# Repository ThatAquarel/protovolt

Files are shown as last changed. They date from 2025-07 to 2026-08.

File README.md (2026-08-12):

[ProtoV MINI][website]

# A power supply to catalyze prototyping

[][release]
[][ci]
[][chat]
[][cs]

**ProtoV MINI** is a credit card-sized, dual-channel lab power supply for
electronics prototyping and field testing. It is powered by USB-C PD and runs
open firmware written in Rust.

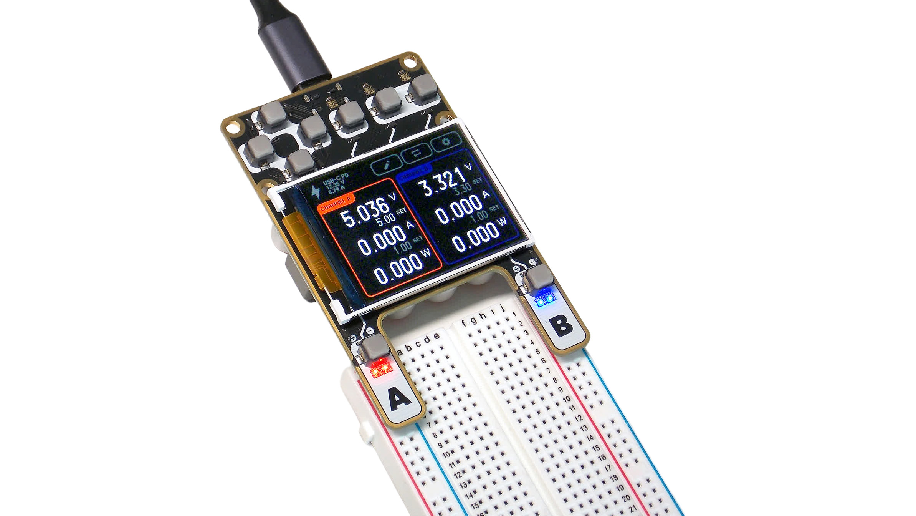
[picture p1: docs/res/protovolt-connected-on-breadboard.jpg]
ProtoV MINI powering a breadboard


## Getting Started

Start with the [quick-start guide](docs/quick_start.md) to connect a USB-C PD
power supply, optionally link ProtoV MINI to a computer, and open
[ProtoV App](https://protov.app).

## Development

```sh
git clone https://github.com/flakeblade/protov.git
cd protov
rustup target add thumbv6m-none-eabi
cargo install just
just build
```
See [development](#development-1) for prerequisites, tests, and common
commands. Run `just --list` to see every available recipe.

## Documentation

### Guides

- [Device overview](docs/product.md) — hardware overview, and dimensions
- [Quick start](docs/quick_start.md) — quickstart wiring guide
- [Interface guide](docs/interface_guide.md) — normal UI flow with example screens
- [Troubleshooting](docs/troubleshooting.md) — faults, protection, and boot failures

### Development

Project structure
- [Repository index, and workspace modules](docs/repository.md)
- [Firmware roadmap](docs/roadmap.md)

Installation, building, and uploading
1. [Toolchain installation, and building](docs/development.md)
2. [Release bundling, and firmware signature](docs/releases.md)
3. [Flashing to hardware](docs/flashing.md)

### References

Hardware compatibility
- [Power delivery sources](docs/compatibility.md)
- [Breadboards](docs/compatibility.md)

Design documentation
- [Hardware and dimensions](docs/hardware.md)
- [SCPI protocol reference](protov-scpi/PROTOCOL.md)

Support
- [Troubleshooting](docs/troubleshooting.md)

<!-- - [Product overview](docs/product.md)
    
- [Flashing](docs/flashing.md)

- [SCPI protocol](protov-scpi/PROTOCOL.md)
- [SCPI crate](protov-scpi/README.md)
- [Bootloader](protov-bootloader/README.md)
- [Flash layout and firmware verification](protov-nvm/README.md) -->

## Contributing

Bug reports and contributions are welcome in the
[GitHub repository](https://github.com/flakeblade/protov).

> [!WARNING]
> Modifying or uploading firmware is done entirely at your own risk. An
> incompatible image can leave the device inoperable and may require USB
> BOOTSEL or SWD recovery. Bypassing current, voltage, temperature, power, or
> other protection limits can damage ProtoV MINI, connected equipment, or
> wiring and may create an electrical or fire hazard. Verify the hardware
> revision, understand every safety-related change, and test conservatively.

## License

[Eclipse Public License 2.0](LICENSE) © Alex Xia — [@ThatAquarel](http://github.com/thataquarel)

<p align="center">
  <a href="https://flakeblade.com">
    Flake & Blade Robotics Design
  </a>
  <br>
  A Flake &amp; Blade Robotics Design project
</p>

[fbrd]: https://flakeblade.com
[release-badge]: https://github.com/flakeblade/protov/actions/workflows/release.yml/badge.svg
[release]: https://github.com/flakeblade/protov/actions/workflows/release.yml
[ci-badge]: https://github.com/flakeblade/protov/actions/workflows/ci.yml/badge.svg
[ci]: https://github.com/flakeblade/protov/actions/workflows/ci.yml
[chat-badge]: https://img.shields.io/badge/chat-discussions-success.svg
[chat]: https://github.com/flakeblade/protov/discussions
[cs-badge]: https://img.shields.io/badge/Crowd-Supply-099?labelColor=555
[cs]: https://www.crowdsupply.com/flake-and-blade-robotics-design/protov-mini
[cover]: docs/res/logo/protov_mini_cover.svg
[website]: https://protov.app

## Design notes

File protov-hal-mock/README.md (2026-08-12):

# protov-hal-mock

`protov-hal-mock` is a host-side ProtoV MINI simulator. It runs the
[`protov-core`](../protov-core/README.md) product logic without RP2040 hardware
and exposes WebSocket endpoints for
[`protov_app`](https://github.com/flakeblade/protov_app), integration tests,
and protocol development.

## Run

```sh
just build-mock
just run-mock
```

The default listeners are:

- `ws://127.0.0.1:8765` — SCPI transport
- `ws://127.0.0.1:8766` — JSON control and state management

Override them with `--bind`, `--scpi-port`, and `--control-port`, or the
`PROTOV_MOCK_SCPI_PORT` and `PROTOV_MOCK_CTRL_PORT` environment variables.

> [!TIP]
> Use the mock for application and SCPI work before connecting real power
> hardware. It follows the same core state machine and is faster to reset,
> inspect, and automate.

## UI state renders

YAML presets under [`states/`](states) describe full device snapshots (SCPI
channels, interface fields, power input, and UI mode). Extend
[`states/default.yaml`](states/default.yaml) for deltas.

Export headless PNG catalog images for documentation:

```sh
just render-ui
```

This writes PNGs to [`docs/res/ui/`](../docs/res/ui/) and refreshes
[`docs/ui-states.md`](../docs/ui-states.md).

## How it works

The server maintains four independent mock-device slots. A SCPI WebSocket
connection acquires an available slot and releases it when disconnected. The
control endpoint can inspect, load, reset, or release slots with JSON messages.
Ready-made snapshots for common states live under [`states/`](states).

- [`src/main.rs`](src/main.rs) — command-line options and server lifecycle
- [`src/server.rs`](src/server.rs) — listener setup and shutdown
- [`src/pool.rs`](src/pool.rs) — mock-device slots and identities
- [`src/device.rs`](src/device.rs) — simulated device state and command handling
- [`src/ws/scpi.rs`](src/ws/scpi.rs) — SCPI WebSocket sessions
- [`src/ws/control.rs`](src/ws/control.rs) — JSON control WebSocket
- [`src/state/`](src/state) — snapshots and control request schema
- [`src/scpi/`](src/scpi) — framing, routing, tasks, and simulated DFU
- [`src/telemetry.rs`](src/telemetry.rs) — generated measurements
- [`src/render.rs`](src/render.rs) — headless UI render pipeline (`render-ui` feature)

SCPI commands follow the
[ProtoV wire protocol](../protov-scpi/PROTOCOL.md). The mock uses the
[`protov-scpi`](../protov-scpi/README.md) parser and host-compatible types.
Control requests support `ping`, `status`, `reset`, `load`, and `release_all`;
their JSON schema is defined in
[`src/state/schema.rs`](src/state/schema.rs).

## Test

```sh
just test-mock
```

The integration tests under [`tests/`](tests) cover connections, command
dispatch, state isolation, and firmware-update behavior. Select a matching
hardware profile with `hw-a0`, `hw-a1`, or `hw-a2`; A.1 is the default.

See [Development](../docs/development.md) for the full workspace workflow and
[Contributing](../CONTRIBUTING.md) before changing shared behavior.

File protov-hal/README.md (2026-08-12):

# protov-hal

`protov-hal` is the RP2040 application firmware for ProtoV MINI. It connects the
hardware-independent state machine in
[`protov-core`](../protov-core/README.md) to the power converters, measurement
devices, display, buttons, USB, LEDs, watchdog, and flash.

Display rendering lives in [`protov-ui`](../protov-ui/README.md); this crate
implements `HalPlatform` (backlight + RGB LEDs) and an async display wrapper with
boot hold timers.

The crate builds the `protov` binary for `thumbv6m-none-eabi` with
[Embassy](https://embassy.dev/).

## Runtime overview

[`src/main.rs`](src/main.rs) initializes the RP2040 and firmware-update state,
starts USB before slower peripheral setup, configures both power channels, and
runs the main event loop. Hardware, interface, and SCPI events are passed to
`protov-core`; the resulting tasks are dispatched back to the hardware or UI.

Button polling runs on the second RP2040 core. Measurement, temperature, USB,
converter interrupt, and display work is coordinated with Embassy tasks and
channels.

> [!TIP]
> Start with [`src/main.rs`](src/main.rs), then follow an event into
> [`src/app.rs`](src/app.rs), [`src/task.rs`](src/task.rs), and
> [`src/hal/event.rs`](src/hal/event.rs). This shows the boundary between
> product policy and peripheral access.

## Important files

- [`src/main.rs`](src/main.rs) — startup, multicore setup, task spawning, and
  main event loop
- [`src/task.rs`](src/task.rs) — executes display, hardware, and DFU tasks
- [`src/ui_platform.rs`](src/ui_platform.rs) — `HalPlatform` (backlight, WS2812)
- [`src/hal/converter.rs`](src/hal/converter.rs) — TPS55289 output control
- [`src/hal/measure.rs`](src/hal/measure.rs) — INA226 voltage and current
  measurement
- [`src/hal/power/`](src/hal/power) — STUSB4500 setup and USB PD negotiation
- [`src/hal/temperature.rs`](src/hal/temperature.rs) — channel and MCU
  temperature acquisition
- [`src/hal/firmware.rs`](src/hal/firmware.rs) — signed SCPI DFU writes and
  verification
- [`src/scpi/usb.rs`](src/scpi/usb.rs) — USB CDC transport and update payload
  assembly
- [`src/hal/factory_program.rs`](src/hal/factory_program.rs) — manufacturing
  identity programming
- [`src/hal/watchdog.rs`](src/hal/watchdog.rs) — boot and runtime watchdog
- [`build.rs`](build.rs) — application linker setup and factory-record
  generation

Flash partitions and trusted keys are defined by
[`protov-nvm`](../protov-nvm/README.md), with the trust model documented in
[`protov-nvm/keys`](../protov-nvm/keys/README.md). SCPI syntax is defined by
[`protov-scpi`](../protov-scpi/README.md), and boot behavior is documented in
[`protov-bootloader`](../protov-bootloader/README.md).

## Build and flash

Hardware revision A.1 is the default:

```sh
just build
just run
```

Select another revision explicitly:

```sh
just build-a0
just build-a1
just build-a2
```

Enable exactly one hardware feature. See
[Development](../docs/development.md) for prerequisites,
[Flashing](../docs/flashing.md) for upload and debug options, and
[Release builds](../docs/releases.md) for signed artifacts.

The optional `demo` feature changes the startup presentation. The
`factory-program` feature enables one-shot manufacturing identity programming;
use `just factory-run` (flash) or `just factory-build` (build only).

Factory builds require identity env vars (`SERIAL_NUMBER`, `HARDWARE_REV`,
`FACTORY_YEAR`, `FACTORY_MONTH`, `FACTORY_DAY`) and either a precomputed
`SIGNATURE` or `HW_PRIVATE_KEY` + `HW_PUBLIC_KEY` PEM pair. The just recipes
source [`scripts/sign-helpers.sh`](../scripts/sign-helpers.sh), which signs the
canonical attestation message from `encode_attestation_message`
(`{serial},{hw_revision},{YYYY-MM-DD}` — must match
`protov_nvm::encode_attestation_message`) before Cargo runs. Do not enable
`factory-program` in normal firmware builds.

> [!WARNING]
> This crate directly controls power hardware. Confirm pin mappings, register
> values, limits, and calibration against the applicable datasheets and
> [hardware revision](../docs/repository.md#hardware-revisions). Protection
> changes must follow the
> [contribution requirements](../CONTRIBUTING.md#feature-changes-1x0).

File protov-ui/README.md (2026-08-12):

# protov-ui

Hardware-agnostic embedded-graphics UI for ProtoV MINI. This crate renders the
320×240 landscape panel from [`DisplayTask`](../protov-core/src/model/types.rs)
values in [`protov-core`](../protov-core/README.md); it does not talk to SPI,
backlight PWM, or WS2812 LEDs directly.

## Public API

| Module / type | Role |
|---|---|
| `DisplayGeometry` | Logical panel size (default 320×240) |
| `ChannelAppearance` | Channel colors and LED tints (impl for `ScpiState`) |
| `UiPlatform` | Backlight and RGB LED side effects |
| `NullPlatform` | No-op platform for simulation |
| `UiRenderer` | Sync draw state over any `DrawTarget<Color = Rgb565>` |
| `dispatch_display_task` | Sync task dispatcher (no boot timers) |

## Modules

- `boot`, `controls`, `navbar`, `settings` — screen drawing
- `theme`, `labels`, `fonts`, `layout` — shared styling and geometry
- `dispatch` — maps `DisplayTask` to renderer calls

## Build

`no_std` crate; builds for host check and embedded targets:

```sh
cargo build -p protov-ui --target x86_64-unknown-linux-gnu
cargo build -p protov-ui --target thumbv6m-none-eabi
```

Optional `demo` feature shows a demo-build banner on the boot screen.

## Extension points

- **Alternate panel size** — pass a custom `DisplayGeometry` to `UiRenderer::new`
- **Different host link indicator** — implement `UiPlatform::serial_connected`
- **Custom channel colors** — implement `ChannelAppearance` instead of using
  `ScpiState` directly

## Consumers

- [`protov-hal`](../protov-hal/README.md) — `HalPlatform` drives backlight and
  WS2812 LEDs; async wrapper adds boot hold timers
- [`protov-hal-mock`](../protov-hal-mock/README.md) — optional `display`
  feature renders to an SDL window via `NullPlatform`

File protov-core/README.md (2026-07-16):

# protov-core

`protov-core` contains the hardware-independent product logic shared by the
RP2040 firmware, host tests, and simulator. It is `no_std` outside tests and
does not access peripherals directly.

Events enter [`AppCore`](src/app/mod.rs), which updates product state and emits
typed display or hardware tasks. [`protov-hal`](../protov-hal/README.md)
executes those tasks on the device;
[`protov-hal-mock`](../protov-hal-mock/README.md) executes equivalent 
behavior on a host.

## Important files

- [`src/app/mod.rs`](src/app/mod.rs) — main state machine, event handling, SCPI
  behavior, and task generation
- [`src/model/`](src/model) — shared events, states, channel types, and tasks
- [`src/config/`](src/config) — product identity, defaults, limits, telemetry,
  and provisioned factory data
- [`src/config/hardware/`](src/config/hardware) — revision-specific analog and
  calibration constants
- [`src/protection.rs`](src/protection.rs) — voltage, current, and temperature
  protection decisions
- [`src/pd/`](src/pd) — USB PD source-capability parsing and selection
- [`src/scpi/`](src/scpi) — device-side SCPI state, responses, telemetry, and
  integration with [`protov-scpi`](../protov-scpi/README.md)
- [`src/dfu/`](src/dfu) — transport-independent firmware-update session state

The complete wire protocol lives in the
[SCPI protocol reference](../protov-scpi/PROTOCOL.md).

## Hardware profiles

Enable exactly one of `hw-a0`, `hw-a1`, or `hw-a2`. The profiles correspond to
the revisions in the
[hardware revision table](../docs/repository.md#hardware-revisions).

```sh
just test-a0
just test-a1
just test-a2
```

Use `test-harness` for host integration tests. The `simulator` feature includes
that harness and is used by `protov-hal-mock`.

Behavioral tests are colocated with their modules. The public-API harness lives
in [`tests/integration.rs`](tests/integration.rs) with support code in
[`tests/support/`](tests/support). Generate a coverage report with:

```sh
just coverage
```

> [!TIP]
> Put product behavior in `protov-core` whenever it can be expressed without
> RP2040 peripherals. It becomes easier to test across every hardware revision
> and reuse in the simulator.

> [!IMPORTANT]
> Changes to limits or protection behavior require tests and electrical
> justification. See the
> [contribution requirements](../CONTRIBUTING.md#feature-changes-1x0).

See [Development](../docs/development.md) for workspace commands and
[`protov-hal`](../protov-hal/README.md) for the device-side implementation.

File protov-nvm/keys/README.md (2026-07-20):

# Protov Firmware Signing Keys

This directory contains the **public** keys used to verify signed firmware,
hardware serial attestations, and trust manifests for Protov devices. All keys
are Ed25519. Raw key files are exactly 32 bytes (one key) or a multiple of 32
bytes (concatenated keys), with no PEM/ASN.1 wrapper — just the raw key bytes.

**Only public keys live here.** The corresponding private keys are never
committed and are held offline / in CI secrets — see "Trust model" below.

## Files

| File | Size | Contents |
|---|---|---|
| `protov_public.key` | 32 bytes | **Master (root) public key.** Verifies trust manifests below. Kept offline; almost never rotates. |
| `protov_public_CIx.key` | 96 bytes | Three concatenated 32-byte **CI signing public keys** (CI0, CI1, CI2, in that order). These verify individual signed firmware releases. |
| `protov_public_CIx.key.sig` | 64 bytes | Root signature over `protov_public_CIx.key`. |
| `protov_public_HWx.key` | 96 bytes | Three concatenated 32-byte **hardware attestation public keys** (HW0, HW1, HW2, in that order). These verify signatures over device serial numbers and related manufacturing records. |
| `protov_public_HWx.key.sig` | 64 bytes | Root signature over `protov_public_HWx.key`. |

## Trust model

### Firmware releases (CIx)

```
MASTER KEY (offline, cold storage)
   │ signs
   V
CI TRUST MANIFEST  (protov_public_CIx.key + .sig)
   │ authorizes
   V
CI SIGNING KEY(S)  (live in GitHub Actions secrets, used by CI on release)
   │ signs
   V
FIRMWARE IMAGE  (what actually gets flashed to a device)
```

- The **master key** never touches CI or the internet. It only ever signs
  a new trust manifest when the set of valid CI keys changes (rotation or
  revocation).
- The **CI keys** are the day-to-day firmware signers. Each release build is
  signed by whichever CI key is currently active. If a CI key is ever suspected
  compromised, it's dropped from a newly-signed trust manifest and firmware
  built with it stops being trusted — without needing physical device access.
- The device bootloader hardcodes the master public key, so it can verify the
  CI manifest, and in turn trusts whichever CI keys that manifest currently
  lists.

### Hardware serial attestation (HWx)

```
MASTER KEY (offline, cold storage)
   │ signs
   V
HW TRUST MANIFEST  (protov_public_HWx.key + .sig)
   │ authorizes
   V
HW SIGNING KEY(S)  (held in manufacturing / provisioning tooling)
   │ signs
   V
SERIAL ATTESTATION  (device serial number and related manufacturing data)
```

- The **HW manifest** uses the same root key and manifest format as CIx (96
  bytes = three Ed25519 public keys), but authorizes a separate key set used
  only for manufacturing workflows.
- **HW keys** sign the canonical attestation message `{serial},{hw_revision},{YYYY-MM-DD}`
  at production time. Any verifier with the embedded root key can confirm that a
  serial was signed by one of the currently trusted HW keys.
- Rotating or revoking an HW key follows the same process as CI: the master
  key signs a new `protov_public_HWx.key` manifest; verifiers reject
  attestations from keys no longer listed.

## Verifying a signature with OpenSSL

OpenSSL's `pkeyutl` needs an Ed25519 public key wrapped in a minimal
DER/PEM structure (SubjectPublicKeyInfo), not the bare 32 raw bytes. The
prefix below is fixed for all Ed25519 keys — just prepend it to the raw key.

**1. Convert a raw 32-byte public key to PEM (one-time, per key):**

```bash
# Master key
( printf '\x30\x2a\x30\x05\x06\x03\x2b\x65\x70\x03\x21\x00'; cat protov_public.key ) \
  > /tmp/protov_public.der
openssl pkey -pubin -inform DER -in /tmp/protov_public.der \
  -outform PEM -out /tmp/protov_public.pem
```

For a CI or HW key, extract the 32 bytes you want first (e.g. slot 0 = first
32 bytes of the concatenated manifest file):

```bash
# CI0 / HW0 = bytes 0-31, slot 1 = bytes 32-63, slot 2 = bytes 64-95
dd if=protov_public_CIx.key of=/tmp/ci0.key bs=1 skip=0  count=32
dd if=protov_public_HWx.key of=/tmp/hw0.key bs=1 skip=0  count=32

( printf '\x30\x2a\x30\x05\x06\x03\x2b\x65\x70\x03\x21\x00'; cat /tmp/ci0.key ) \
  > /tmp/ci0.der
openssl pkey -pubin -inform DER -in /tmp/ci0.der -outform PEM -out /tmp/ci0.pem
```

**2. Verify a signature (raw Ed25519, no pre-hashing):**

```bash
# Verify a trust manifest, signed by the master key
openssl pkeyutl -verify -pubin -inkey /tmp/protov_public.pem \
  -rawin -in protov_public_CIx.key -sigfile protov_public_CIx.key.sig

openssl pkeyutl -verify -pubin -inkey /tmp/protov_public.pem \
  -rawin -in protov_public_HWx.key -sigfile protov_public_HWx.key.sig

# Verify a firmware image, signed by a CI key
openssl pkeyutl -verify -pubin -inkey /tmp/ci0.pem \
  -rawin -in firmware.bin -sigfile firmware.sig

# Verify a serial attestation, signed by an HW key
# Message bytes: {serial},{hw_revision},{YYYY-MM-DD}  e.g. 550e8400,A.1,2026-06-27
printf '%s' '550e8400,A.1,2026-06-27' > /tmp/serial_record.bin
openssl pkeyutl -verify -pubin -inkey /tmp/hw0.pem \
  -rawin -in /tmp/serial_record.bin -sigfile serial_record.sig
```

On a connected device, query the provisioned attestation with `SYST:IDAT?` (see
`protov-scpi/PROTOCOL.md`). Host tools verify the response with
`protov_nvm::verify_serial_attestation(serial, &signature_bytes)`.

A successful check prints `Signature Verified Successfully`. Anything else
means the file, key, or signature don't match — do not trust the artifact.

## Rotating or revoking a CI or HW key

If a CI or HW key needs to be replaced (routine rotation, or a suspected leak):

1. A new keypair is generated and its public key added to the manifest file.
2. The master key (offline) signs the updated manifest (`*.key.sig`).
3. For CI keys, the new manifest ships as part of the next signed firmware
   release; devices refresh their trusted CI key set after verifying the
   manifest against the hardcoded root key.
4. For HW keys, manufacturing tooling picks up the new manifest so newly
   issued serial attestations use the current trusted key set.

The master key itself is not expected to rotate under normal operation.

## Generating your own keys

Use this workflow to build a custom trust chain for development or a
forked release process. The stock keys in this directory are for official
ProtoV builds only. Never commit private keys.

> [!CAUTION]
> Private keys must stay offline or in CI secrets. Pull requests that add or
> replace trusted public keys receive additional review; see
> [Signing](../../docs/releases.md#signing) and
> [Custom keys and unsigned firmware](../../docs/releases.md#custom-keys-and-unsigned-firmware).

All examples use OpenSSL Ed25519 keys. Raw public-key files must be exactly
32 bytes each. Manifests are three raw keys concatenated (`cat`), in slot
order 0, 1, then 2.

### 1. Generate keypairs

Generate a root (master) key and one keypair per CI or HW slot:

```bash
# Root (master) key — keep offline
openssl genpkey -algorithm ed25519 -out protov_private.pem

# CI signing keys (CI0, CI1, CI2)
openssl genpkey -algorithm ed25519 -out protov_private_CI0.pem
openssl genpkey -algorithm ed25519 -out protov_private_CI1.pem
openssl genpkey -algorithm ed25519 -out protov_private_CI2.pem

# Hardware attestation keys (HW0, HW1, HW2), if needed
openssl genpkey -algorithm ed25519 -out protov_private_HW0.pem
openssl genpkey -algorithm ed25519 -out protov_private_HW1.pem
openssl genpkey -algorithm ed25519 -out protov_private_HW2.pem
```

### 2. Export public keys

PEM public keys are useful for OpenSSL tooling. Raw `.key` files are what
firmware embeds:

```bash
# Root public key as PEM (for signing/verifying manifests)
openssl pkey -in protov_private.pem -pubout -out protov_public.pem

# Example: PEM public key for an HW slot
openssl pkey -in protov_private_HW2.pem -pubout -out protov_public_HW2.pem

# Raw 32-byte public keys (last 32 bytes of the DER SubjectPublicKeyInfo)
openssl pkey -in protov_private.pem -pubout -outform DER \
  | tail -c 32 > protov_public.key

openssl pkey -in protov_private_CI0.pem -pubout -outform DER \
  | tail -c 32 > protov_public_CI0.key
openssl pkey -in protov_private_CI1.pem -pubout -outform DER \
  | tail -c 32 > protov_public_CI1.key
openssl pkey -in protov_private_CI2.pem -pubout -outform DER \
  | tail -c 32 > protov_public_CI2.key

openssl pkey -in protov_private_HW0.pem -pubout -outform DER \
  | tail -c 32 > protov_public_HW0.key
openssl pkey -in protov_private_HW1.pem -pubout -outform DER \
  | tail -c 32 > protov_public_HW1.key
openssl pkey -in protov_private_HW2.pem -pubout -outform DER \
  | tail -c 32 > protov_public_HW2.key
```

Confirm each raw key is 32 bytes (`wc -c protov_public_CI0.key` should print
`32`).

### 3. Build CI and HW manifests

Concatenate the three slot public keys in order:

```bash
cat protov_public_CI0.key protov_public_CI1.key protov_public_CI2.key \
  > protov_public_CIx.key

cat protov_public_HW0.key protov_public_HW1.key protov_public_HW2.key \
  > protov_public_HWx.key
```

Each manifest must be exactly 96 bytes.

### 4. Sign the manifests with the root key

The root private key signs each concatenated manifest:

```bash
openssl pkeyutl -sign -inkey protov_private.pem -rawin \
  -in protov_public_CIx.key -out protov_public_CIx.key.sig

openssl pkeyutl -sign -inkey protov_private.pem -rawin \
  -in protov_public_HWx.key -out protov_public_HWx.key.sig
```

### 5. Verify the manifest signatures

```bash
openssl pkeyutl -verify -pubin -inkey protov_public.pem -rawin \
  -in protov_public_CIx.key -sigfile protov_public_CIx.key.sig

openssl pkeyutl -verify -pubin -inkey protov_public.pem -rawin \
  -in protov_public_HWx.key -sigfile protov_public_HWx.key.sig
```

A successful check prints `Signature Verified Successfully`.

### 6. Install the public artifacts

Copy the public files into this directory (or your fork's equivalent):

| Generated file | Role |
| --- | --- |
| `protov_public.key` | Root public key embedded in firmware |
| `protov_public_CIx.key` | CI trust manifest |
| `protov_public_CIx.key.sig` | Root signature over the CI manifest |
| `protov_public_HWx.key` | HW trust manifest |
| `protov_public_HWx.key.sig` | Root signature over the HW manifest |

Then rebuild firmware so the new keys are compiled in, flash that first image
through [USB BOOTSEL](../../docs/flashing.md#option-2-usb-bootsel) or
[SWD](../../docs/flashing.md#option-3-swd-debug-probe), and sign later DFU
releases with an authorized CI private key (`PRIVATE_KEY` / `PUBLIC_KEY` as
described in [Release builds](../../docs/releases.md#signing)).

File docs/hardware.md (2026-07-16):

# Hardware

ProtoV MINI is an open-hardware, credit card-sized dual-channel power supply.
For electrical and mechanical specifications, see the
[product overview](product.md#specifications).

## Design resources

The editable hardware design is available in the repository's
[`hardware/`](../hardware/) directory and is created with
[KiCad](https://www.kicad.org/).

| Resource | Location |
| --- | --- |
| ProtoV MINI KiCad project | [`hardware/mini/`](../hardware/mini/) |
| Main schematic | [`mini.kicad_sch`](../hardware/mini/mini.kicad_sch) |
| PCB project settings | [`mini.kicad_pro`](../hardware/mini/mini.kicad_pro) |
| Custom footprints and 3D models | [`protovolt_mini.pretty/`](../hardware/mini/protovolt_mini.pretty/) |
| Hardware revision guide | [Repository guide](repository.md#hardware-revisions) |

> [!TIP]
> Open `mini.kicad_pro` in KiCad to load the complete project and its
> hierarchical schematics.

## Hardware overview

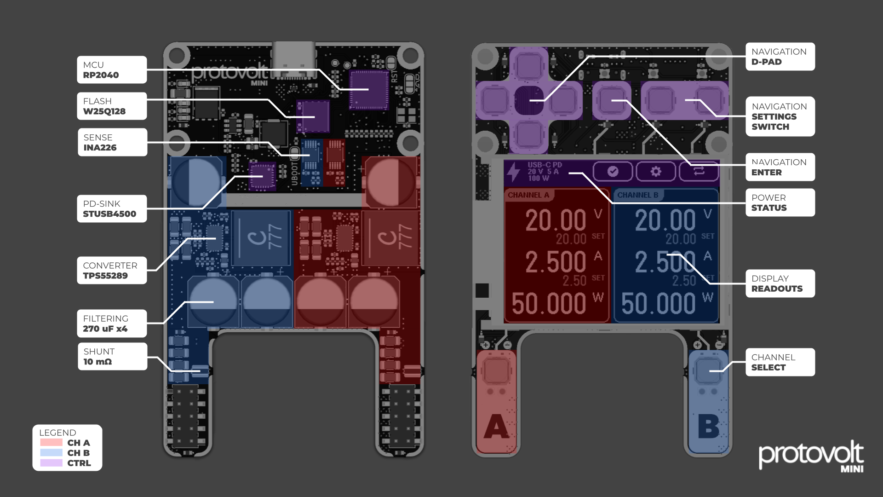
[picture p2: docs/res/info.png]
ProtoV MINI hardware overview


The overview render identifies ProtoV MINI's connectors, display, controls,
output channels, and other user-accessible hardware.

## Dimensions

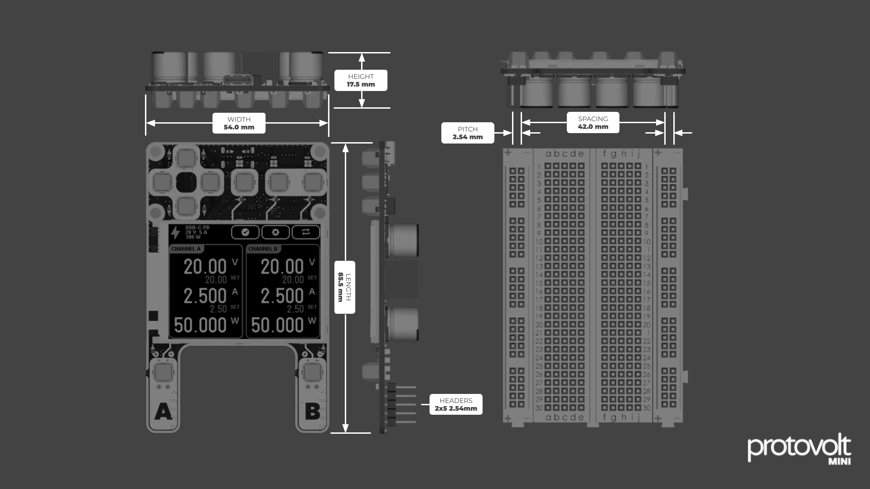
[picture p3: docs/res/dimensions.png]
ProtoV MINI dimensions


ProtoV MINI measures **85.5 × 54 × 18 mm**. Additional specifications are
listed in the [product overview](product.md#specifications).

> [!NOTE]
> The renders are visual references. Use the KiCad design files when exact
> mechanical placement or manufacturing data is required.

For first-time setup, continue to the [quick-start guide](quick_start.md). For
tested power supplies, breadboards, browsers, and operating systems, see the
[compatibility guide](compatibility.md).

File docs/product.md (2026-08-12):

# Product overview

Start here:

- [Quick start](quick_start.md) — connect USB-C PD power and optionally link a computer
- [Interface guide](interface_guide.md) — screen-by-screen UI walkthrough with example renders

ProtoV MINI is a portable lab power supply designed for electronics
prototyping and field testing.

## Features

- Two independent, adjustable output channels
- USB-C Power Delivery input
- Credit card-sized enclosure
- D-pad and control-button interface
- Open Rust firmware and KiCad hardware design
- Headers compatible with common prototyping breadboards

## Specifications

| | |
| --- | --- |
| Input | USB-C PD 2.0, up to 100 W |
| Outputs | 2 adjustable channels |
| Voltage | 0–20 V in 10 mV steps |
| Current | 0–5 A in 50 mA steps |
| Dimensions | 85.5 × 54 × 18 mm |
| Display | 2-inch, 320 × 240 TFT |
| Controls | D-pad and control buttons |
| MCU | RP2040 |

## Hardware

Each channel uses an independent buck-boost power path. The USB-C input
negotiates up to 100 W, while the RP2040 controls output regulation,
measurement, protection, and the user interface.

The two 2×5, 2.54 mm-pitch output headers align with the power rails on BB400
and BB830 breadboards.

## Gallery

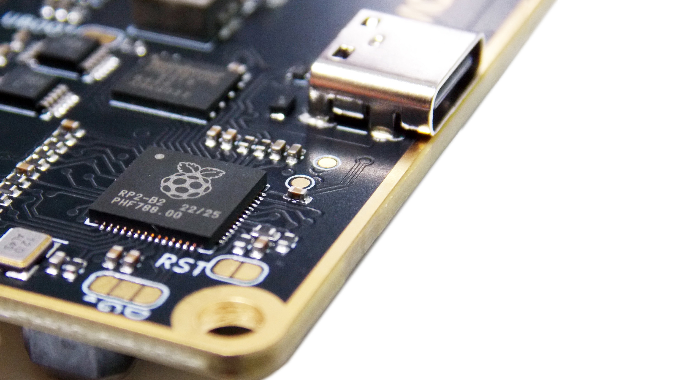
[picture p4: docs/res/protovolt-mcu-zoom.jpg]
MCU detail


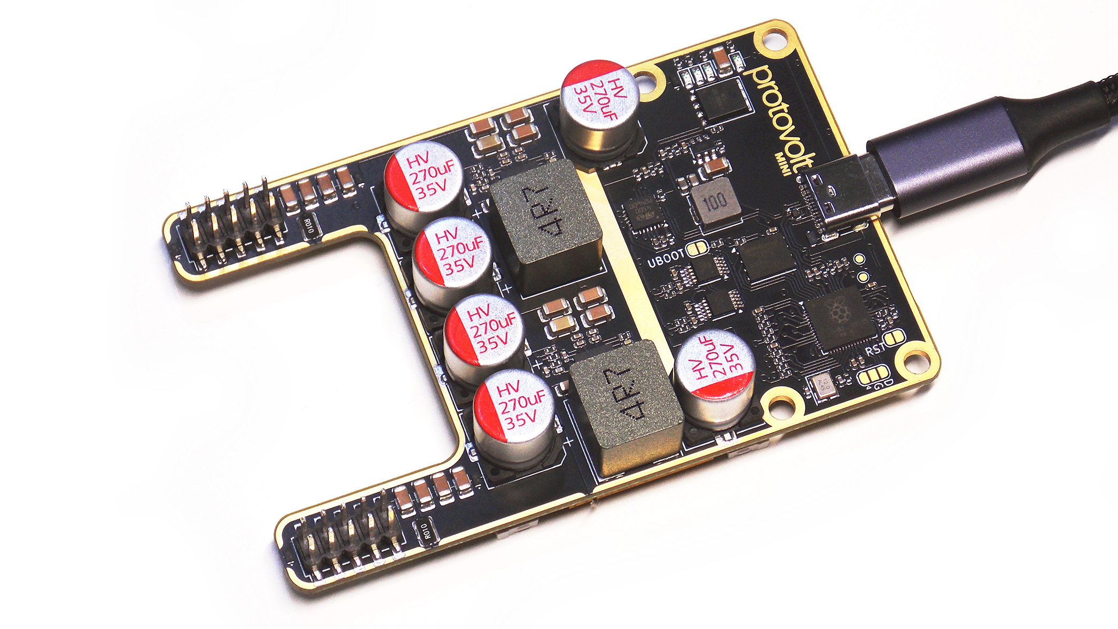
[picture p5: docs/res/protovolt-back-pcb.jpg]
Back of the PCB


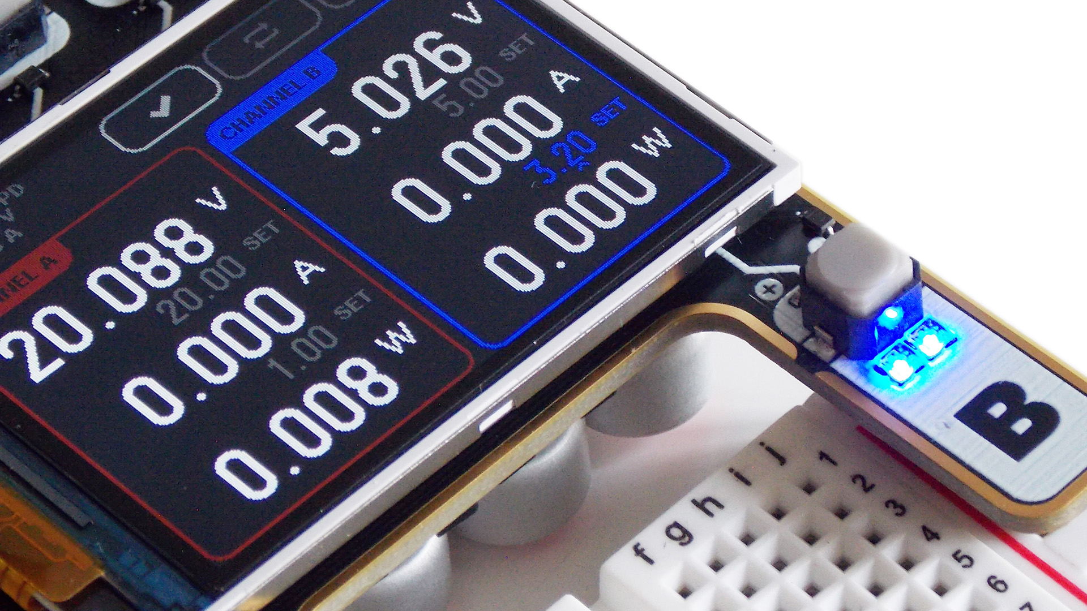
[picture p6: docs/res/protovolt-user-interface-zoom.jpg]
User interface


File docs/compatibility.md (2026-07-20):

# Compatibility

## USB-C power sources

ProtoV MINI uses the **STUSB4500** USB-C Power Delivery sink controller. It
negotiates power over the USB-C Configuration Channel (CC) pins and is designed
to work with most standards-compliant, fixed-supply USB PD sources.

The USB D+ and D− data lines are routed directly to the RP2040 for device
communication.

> [!NOTE]
> ProtoV MINI therefore does not support Qualcomm Quick Charge or
> other charging standards that negotiate voltage over the USB data lines.
> Power-source negotiation must use the USB-C CC pins.

## Tested power sources

The following list is not exhaustive and will expand as more sources are
tested.

| Source type | Manufacturer | Product and model | Test condition | Negotiated contract | RDO | Position | Software | Tested by |
| --- | --- | --- | --- | --- | --- | --- | --- | --- |
| USB PD | Anker | Laptop Charger 140W, 4-Port, PD 3.1 (A2697) | Port C3 | 20.0 V, 2.0 A, 40.0 W | `0x400320c8` | 4 | 1.7.3 | [@ThatAquarel](https://github.com/ThatAquarel) |
| USB PD | Anker | Laptop Charger 140W, 4-Port, PD 3.1 (A2697) | Port C1 or C2 | 20.0 V, 5.0 A, 100.0 W | `0x4007d1f4` | 4 | 1.7.3 | [@ThatAquarel](https://github.com/ThatAquarel) |
| USB PD | Dell | XPS 9315 45W Charger (DA45NM210) | USB-C | 20.0 V, 2.25 A, 45.0 W | `0x400384e1` | 4 | 1.7.3 | [@ThatAquarel](https://github.com/ThatAquarel) |
| USB PD | Lenovo | ThinkPad X1 Carbon Gen 11 65W Charger (ADLX65YDC3E) | USB-C | 20.0 V, 3.25 A, 65.0 W | `0x40051545` | 4 | 1.7.3 | [@ThatAquarel](https://github.com/ThatAquarel) |
| Standard USB | Anker | PowerCore 10K (A1229) | Standard/PD | 5.0 V, 3.0 A, 15.0 W | — | — | 1.7.3 | [@ThatAquarel](https://github.com/ThatAquarel) |
| Standard USB | Dell | XPS 13 9360 laptop USB Type-A | Standard/PD | 5.0 V, 0.5 A, 2.5 W | — | — | 1.7.3 | [@ThatAquarel](https://github.com/ThatAquarel) |

> [!TIP]
> Tested a power source that is not listed here? Open a
> [tested power source](https://github.com/flakeblade/protov/issues/new?template=power-source.yml)
> issue with the values shown on ProtoV MINI so it can be added to this table.

## Breadboards

ProtoV MINI's 2×5 output headers use a 2.54 mm pitch and align with the power
rails on common BB400- and BB830-style solderless breadboards. Generic,
inexpensive breadboards are being tested, but their contact material, grip,
resistance, and safe current capacity vary significantly.

The following higher-quality BusBoard Prototype Systems models provide more
consistent contacts and publish electrical ratings:

| Breadboard | Fit | Published rating | Notes |
| --- | --- | --- | --- |
| [BB400](https://www.busboard.com/BB400) | Direct fit | 36 V, 2 A | Compact 400-point board |
| [BB830](https://www.busboard.com/BB830) | Direct fit | 36 V, 2 A | Full-size 830-point board |

Stay within the breadboard manufacturer's rating and derate unknown or
inexpensive boards further. High contact resistance can cause voltage drop and
localized heating; stop using a connection if it becomes warm, loose, or
discolored. Use appropriately rated wiring, connectors, or a soldered PCB for
sustained high-current loads.

> [!CAUTION]
> Do not assume that a solderless breadboard can carry ProtoV MINI's full 5 A
> output.

## ProtoV App

[ProtoV App](https://protov.app) communicates with the device through the Web
Serial API. Browser implementation and adoption are tracked by
[Can I use: Web Serial](https://caniuse.com/web-serial).

| Operating system | Browser | Test status |
| --- | --- | --- |
| Windows | Chrome | Tested |
| Windows | Edge | Tested |
| Windows | Firefox | Tested with Web Serial-capable versions |
| Linux | Chrome | Tested |
| Linux | Firefox | Limited; behavior and device access can be unreliable |
| macOS / iOS | Safari | Not supported |

Browser support can change between releases. Use a current Chromium-based
browser when reliable device access is required.

> [!TIP]
> Please submit an issue to the [`protov_app`](https://github.com/flakeblade/protov_app)
> repository for platform-support related inquiries, or open up a discussion in the
> current repository.

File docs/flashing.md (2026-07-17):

# Flashing

## Option 1: DFU over SCPI

For normal firmware updates, use [ProtoV App](https://protov.app). It downloads
the signed release for your hardware revision and sends it to the device over
USB. The device verifies the signature before applying the update.

See [Release builds](releases.md) for signing details and instructions for
using your own keys and ProtoV App build.

### Manual SCPI upload

You can download the matching `.bin` and `.sign.bin` files from
[GitHub Releases](https://github.com/flakeblade/protov/releases), then upload
them with [`scripts/fwup_upload.py`](../scripts/fwup_upload.py):

```sh
pip install pyserial
python scripts/fwup_upload.py \
  --port /dev/ttyACM0 \
  --firmware dist/A.1/protov-1.7.3-A.1.bin \
  --signature dist/A.1/protov-1.7.3-A.1.sign.bin
```

Replace the port, version, paths, and hardware revision as needed.

> [!CAUTION]
> Prefer ProtoV App. The manual uploader is a low-level development tool and
> provides fewer safeguards against selecting the wrong artifacts.

## Option 2: USB BOOTSEL

USB BOOTSEL bypasses the installed application and copies a UF2 image through
the RP2040 ROM bootloader.

> [!IMPORTANT]
> Use a UF2 built for the correct hardware revision. Incorrect pin mappings,
> flash layouts, or power-control behavior can damage the device or connected
> hardware. Determine your revision from the
> [hardware revision table](repository.md#hardware-revisions) before building
> or downloading an image.

Generate the UF2 for the required revision:

```sh
just build-a0    # or build-a1 / build-a2
just pkg

```
See [Release builds](releases.md) for complete release bundles. A generated
development image is written to `target/protov.uf2`.

To package the bootloader itself as UF2, run:

```sh
just bootloader::pkg
```

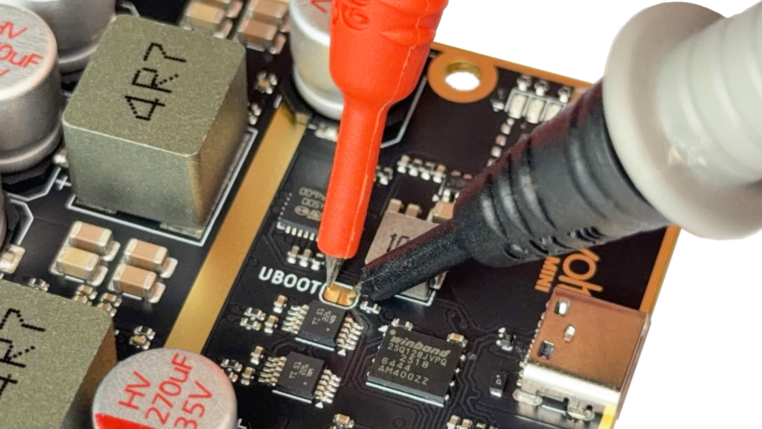
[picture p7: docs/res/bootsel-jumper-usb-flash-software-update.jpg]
Shorting UBOOT jumper

*Shorting the UBOOT jumper with a multimeter in current measurement mode. Shorting the jumper while powering the device over USB allows for BOOTSEL mode flashing.*

To enter BOOTSEL mode:

1. Unplug USB from ProtoV MINI.
2. Short the two pads of the `UBOOT` jumper.
3. Keep the jumper shorted while plugging in USB.
4. Wait a few seconds for the RP2040 mass-storage
   device to enumerate. Remove the short.
5. Copy the correct `.uf2` file to the mounted drive. The device disconnects
   and reboots automatically after the copy completes.

> [!TIP]
> A multimeter in current-measurement mode can be used as a temporary dead
> short: touch one probe to each `UBOOT` pad before connecting USB. This can be
> easier than holding a small wire or tweezers. Remove the probes after
> connecting USB, and immediately return the multimeter lead and selector to
> voltage mode. Leaving it configured for current measurement can short the
> next circuit you test and blow the meter fuse.

## Option 3: SWD debug probe

SWD is intended for development, debugging, and device recovery. The wiring
principles are shown on page 18 of Raspberry Pi's
[Getting started with Raspberry Pi Pico](https://pip-assets.raspberrypi.com/categories/610-raspberry-pi-pico/documents/RP-008276-DS-2-getting-started-with-pico.pdf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).

Compatible probes supported by [`probe-rs`](https://probe.rs/docs/getting-started/probe-setup/)
include:

- [Raspberry Pi Debug Probe](https://www.raspberrypi.com/documentation/microcontrollers/debug-probe.html)
  (CMSIS-DAP)
- A Raspberry Pi Pico running the Raspberry Pi `debugprobe` firmware
  (CMSIS-DAP)
- SEGGER J-Link probes
- ST-Link V2 and V3 probes
- Other CMSIS-DAP-compatible probes

Use SWD at 3.3 V logic levels. Connect the probe to the three pads beside the
crystal:

- `D` — SWD data
- `G` — ground
- `<` — SWD clock

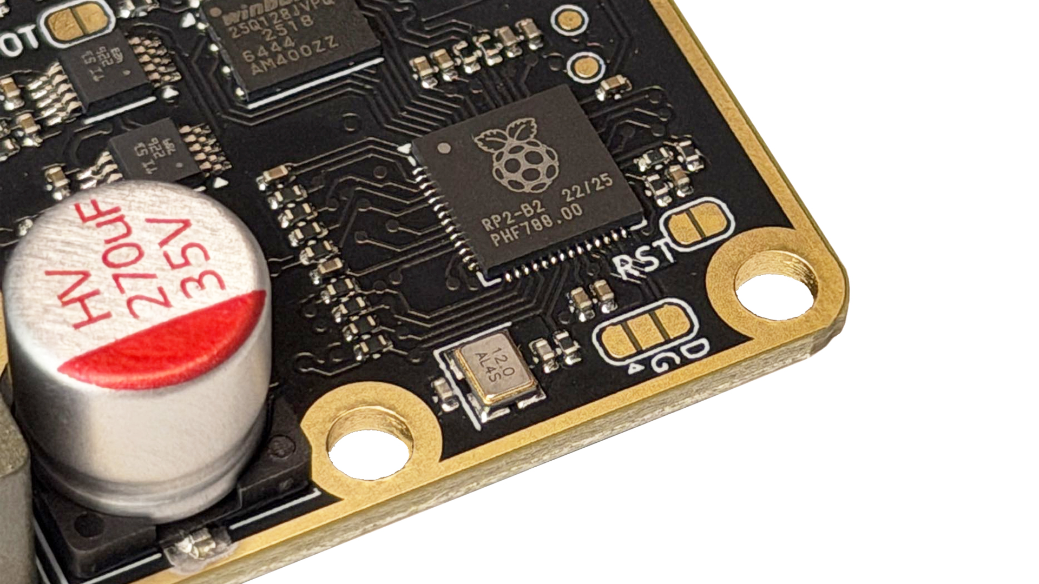
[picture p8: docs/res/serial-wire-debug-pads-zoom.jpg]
SWD Pads

*Serial wire debug pads next to the RP2040 MCU. The hardware reset jumper is also in view: shorting the jumper resets the MCU.*

Soldering temporary wires to these pads is strongly recommended. Holding loose
probe wires against the small pads is difficult and can cause an unreliable
connection during flashing.

Build and flash the firmware for the correct revision:

```sh
just run
```

The default `just run` recipe targets A.1. Use the appropriate Cargo hardware
feature when developing for another revision.

Bootloader commands are separate:

```sh
just bootloader::build
just bootloader::flash
```

## Debugging the bootloader and main firmware

> [!IMPORTANT]
> Do not leave a debug-profile bootloader installed when using `probe-rs`
> logging or debugging on the main firmware. The debugger can remain associated
> with the bootloader's vector-table and debug context instead of attaching
> correctly after control passes to the main firmware.

Debug the [bootloader](../protov-bootloader/README.md) in debug mode when
needed. Before debugging the main firmware, rebuild and flash the bootloader in
release mode:

```sh
just bootloader::build
just bootloader::flash
just run
```

The repository's bootloader recipes include `--release`. Flashing that release
bootloader restores the expected layout and allows `probe-rs` to attach to and
log the main firmware normally.

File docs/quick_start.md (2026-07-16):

# Quick start

ProtoV MINI can be used as a standalone power supply or connected to a
computer for control through [ProtoV App](https://protov.app).

| Setup | What you need | Computer control |
| --- | --- | --- |
| [USB-C PD supply only](#option-1-usb-c-pd-supply-only) | USB-C PD supply and CC-capable USB-C cable | No |
| [USB-C PD supply and computer](#option-2-usb-c-pd-supply-and-computer) | USB-C PD supply, computer, USB-C cables, and USB-C OTG splitter | Yes |

Before starting, check the lists of [tested USB-C power
sources](compatibility.md#usb-c-power-sources) and
[ProtoV App-compatible platforms](compatibility.md#protov-app).

## Option 1: USB-C PD supply only

Use this setup when you want to control ProtoV MINI from its display and
buttons without connecting it to a computer.

1. Connect a USB-C to USB-C cable to a USB-C PD power supply.
2. Connect the other end of the cable to ProtoV MINI's USB-C connector.
3. Wait for the splash screen and confirm that the boot-time power check shows
   a check mark.
4. Check the status in the upper-left corner of the display.

> [!IMPORTANT]
> Use a USB-C cable with Configuration Channel (CC) conductors. A cable without
> the CC connection cannot perform USB-C Power Delivery negotiation.

The display identifies the detected connection:

| Display status | Meaning |
| --- | --- |
| **USB PD** | A USB Power Delivery contract was negotiated |
| **USB 2.0** | The device is receiving standard USB power without a USB PD contract |
| **Linked** | A USB data connection to a computer is active |

Compare the negotiated voltage, current, and power shown on the display with
the power supply's ratings. See [USB-C power-source
compatibility](compatibility.md#usb-c-power-sources) for tested examples and
negotiated contracts.

> [!TIP]
> If the display shows **USB 2.0** when you expected **USB PD**, verify that
> both the supply and cable support USB Power Delivery, then reconnect the
> cable. While ProtoV MINI supports both USB-C connector orientations,
> some lower-quality cables may behave differently when flipped, potentially
> affecting connection stability.

## Option 2: USB-C PD supply and computer

Use a USB-C OTG splitter to power ProtoV MINI from a USB-C PD supply while
connecting its USB data interface to a computer.

> [!IMPORTANT]
> Connect both the power supply and the computer to the splitter **before**
> connecting the splitter to ProtoV MINI. Connecting the branches in a
> different order can cause an incorrect power negotiation.

1. With the splitter disconnected from ProtoV MINI, connect the USB-C PD supply
   to the splitter's power-input port.
2. Connect the computer's USB cable to the splitter's non-power, data-capable
   port.
3. Connect the splitter to ProtoV MINI's USB-C connector.
4. Wait for the splash screen and confirm that the boot-time power check shows
   a check mark.
5. Check the upper-left corner of the display for **USB PD** and **Linked**.
6. Verify that the displayed negotiated voltage, current, and power match the
   expected capabilities of the power supply.
7. Open [ProtoV App](https://protov.app) in a
   [supported browser](compatibility.md#protov-app).
8. Select **Lab**, then select **Connect**.
9. In the browser's device picker, select the serial device enumerated by
   ProtoV MINI and confirm the connection.

> [!TIP]
> If ProtoV MINI does not appear in the device picker, confirm that the
> computer is connected to the splitter's data-capable port and that the
> display shows **Linked**. Browser and operating-system support is documented
> in [ProtoV App compatibility](compatibility.md#protov-app).

For device dimensions, controls, and hardware design resources, see the
[hardware guide](hardware.md).

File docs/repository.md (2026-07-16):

# Repository guide

The hardware is designed with [KiCad 10](https://www.kicad.org/). The firmware
uses the [Embassy](https://embassy.dev/) embedded framework.

| Path | Purpose |
| --- | --- |
| [`protov-core/`](../protov-core/README.md) | Host-testable product logic and state machines |
| [`protov-hal/`](../protov-hal/README.md) | RP2040 firmware, drivers, and user interface |
| [`protov-bootloader/`](../protov-bootloader/README.md) | A/B firmware bootloader |
| [`protov-nvm/`](../protov-nvm/README.md) | Flash layout, factory data, and firmware verification |
| [`protov-scpi/`](../protov-scpi/README.md) | SCPI protocol, host client, and browser WASM build |
| [`protov-hal-mock/`](../protov-hal-mock/README.md) | Host-side WebSocket device simulator |
| `hardware/` | KiCad design files |
| `docs/` | Project documentation and product images |
| `scripts/` | Firmware upload and release-signing helpers |
| `res/` | Project branding |

## Hardware revisions

Hardware revisions A.0, A.1, and A.2 use the `hw-a0`, `hw-a1`, and `hw-a2`
Cargo features. Development commands build A.1 by default.

Each crate keeps detailed implementation documentation next to its source.
Start at the [documentation section](../README.md#documentation).

To determine your hardware revision, and thus the appropriate release to flash, match the details of your hardware to the following table.

| Revision | Stage | Shipment Dates | PCB Logotype | Flash Size | Firmware Size | Notes |
| --- | --- | --- | --- | --- | --- | --- |
| A.0 | Prototyping | 2025 Q2 - 2026 Q1 | `protovolt mini` | 128 MBit (16 MByte) | --- | Faulty CH A/B kelvin sense.
| A.1 | Development | 2026 Q1 - 2026 Q2 | `protovolt mini` | 128 MBit (16 MByte) | --- | Faulty CH A/B kelvin sense (shunt value compensated in software).
| A.2 | Production | TBD |  `protov mini` | 16 MBit (2 MByte) | ~291 kByte (v1.7.3) |

## Software revisions

ProtoV follows [Semantic Versioning](https://semver.org/). All Rust packages share the same version defined in the workspace [Cargo.toml](../Cargo.toml).

- **Major (`x.0.0`)** — breaking changes. ProtoV MINI is stable on v1, and no major
  breaking changes are expected.
- **Minor (`1.x.0`)** — backward-compatible features. Many features are still
  planned; see the [project roadmap](roadmap.md).
- **Patch (`1.0.x`)** — backward-compatible bug fixes. Expect frequent fixes;
  small quality-of-life changes may not receive a standalone release.

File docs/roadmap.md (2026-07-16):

# Roadmap

Planned work is tracked in [GitHub Issues](https://github.com/flakeblade/protov/issues).
Critical and security issues are addressed first, followed by feature
additions, then non-critical bug fixes and quality-of-life improvements.

> [!TIP]
> Feeling inspired to add or fix something? See the
> [contributing guide](../CONTRIBUTING.md).

## Embassy

The current set of [Embassy](https://embassy.dev) versions will remain the supported development
environment. Version bumps are unlikely unless they resolve a significant
issue. Once Embassy reaches a stable `v1.x` release, a major HAL overhaul may be
considered; no such migration is currently planned.

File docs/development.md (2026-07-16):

# Development

## Prerequisites

- A current Rust toolchain
- [`just`](https://github.com/casey/just)
- `probe-rs` for SWD flashing and debugging
- `elf2uf2-rs` for USB flash images
- The `thumbv6m-none-eabi` Rust target
- GNU Arm Embedded `objcopy` for complete release bundles

Install the Rust-based tools and target:

```sh
rustup target add thumbv6m-none-eabi
cargo install just probe-rs-tools elf2uf2-rs
```

## Build firmware

```sh
just build       # A.1, the default
just build-a0
just build-a1
just build-a2
```

## Check changes

```sh
just checks      # all tests, lint, and formatting
just test        # core A.1 and SCPI tests
just clippy
just fmt
```

Individual test recipes are available for every hardware revision and
workspace component. Run `just --list` for the complete list.

## Simulator and browser transport

```sh
just build-mock
just run-mock
just scpi-wasm-build
```

The simulator exposes a WebSocket SCPI bridge for development and end-to-end
testing without hardware.

## Query a connected device

```sh
just scpi-id /dev/ttyACM0
```

The command queries the device identity over USB serial. Replace the port with
the path used by your system.

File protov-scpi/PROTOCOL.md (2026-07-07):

# ProtoV SCPI wire protocol

This document is the **ground-truth reference** for the ProtoV SCPI line protocol as implemented in `protov-scpi`. It is derived directly from `parse.rs`, `policy.rs`, `block.rs`, `types.rs`, and `command.rs`. Device-side semantics (what a command *does*) live in `protov-core`; this crate owns **syntax**, **framing**, and **session policy** on the wire.

## Transport

- **Physical layer:** USB CDC serial (typical host tools) or any byte stream with the same line discipline.
- **Framing:** One command or response per line, terminated by ASCII `LF` (`0x0A`). Hosts may send `CRLF`; parsers trim leading/trailing whitespace before normalization.
- **Encoding:** ASCII command headers. Binary payload for firmware blocks uses IEEE 488.2 definite-length blocks (see [Binary blocks](#binary-blocks)).
- **Line limits:** Normalized commands fit in 256 bytes (`LINE_BUF`). Response text is capped at 512 bytes (`RESPONSE_BUF`) on the device.

## Normalization

Every command passes through `normalize_command` before parsing:

1. Trim leading and trailing whitespace.
2. Uppercase all ASCII letters (`ch1:volt?` → `CH1:VOLT?`).
3. Collapse runs of spaces and tabs to a single space.
4. Strip trailing spaces.

Empty lines after normalization are rejected (`parse_command` returns `None`).

## Identifiers

| Symbol | Accepted tokens | Meaning |
|---|---|---|
| Output channel | `CH1`, `CH2` | Front-panel channels |
| Register channel | `CHA`, `CHB` | I²C rail A / B (maps to hardware channels) |
| Temperature slot | `CHA`, `CHB`, `MCU` | Channel A sense, channel B sense, MCU die |

## Numeric formats

| Type | Grammar | Range / notes |
|---|---|---|
| Integer (slot) | Single digit `1`–`9` | `*SAV`, `*RCL`, `*DEL` |
| Integer (size) | One or more ASCII digits | `SYST:FWUP:STAR`; must fit `u32` |
| Float | Optional `+`/`-`, digits, optional `.` fraction | Channel setpoints; no exponent |
| Brightness | Decimal integer | `0`–`255` for `LCD:BRIG` / `LED:BRIG` |
| RGB triplet | `R,G,B` comma-separated decimals | Each component `0`–`255` |

## Command reference

Commands are listed in the form accepted **after normalization**. `?` suffix denotes a query (host expects a response line). Commands without `?` are mutations unless noted.

### IEEE 488.2 common commands

| Command | Type | Parsed as |
|---|---|---|
| `*IDN?` | Query | Identity string (device-specific) |
| `*RST` | Mutation | Factory reset (silent on bus; errors via `SYST:ERR?`) |
| `*SAV n` | Mutation | Save setup to slot `n` (`n` = `1`–`9`) |
| `*RCL n` | Mutation | Recall setup from slot `n` |
| `*DEL n` | Mutation | Delete saved setup in slot `n` |

Slot commands require exactly one digit after the prefix (e.g. `*SAV 3`). `*SAV 0` or `*SAV 12` does **not** match; such lines fall through to [Unknown](#unknown-commands).

### System

| Command | Type | Notes |
|---|---|---|
| `SYST:ERR?` | Query | Error queue; see [Errors](#errors) |
| `SYST:VERS?` | Query | System / protocol version string |
| `SYST:IDAT?` | Query | Authenticated device identification; see [Device identification](#device-identification) |
| `SYST:LOC` | Mutation | Local front-panel control |
| `SYST:REM` | Mutation | Remote (SCPI) control |

### Device identification

| Command | Type | Response |
|---|---|---|
| `*IDN?` | Query | Full identity string (manufacturer, product, serial, firmware, hardware) |
| `SYST:IDAT?` | Query | Serial number, hardware revision, manufacturing date, flash unique ID, and Ed25519 serial attestation signature |

`*IDN?` returns a comma-separated identity line (see [IEEE 488.2 common commands](#ieee-4882-common-commands)).

`SYST:IDAT?` returns authenticated manufacturing identity for host verification against the
embedded HW trust manifest (`protov-nvm`):

```
{serial},{hw_version},{YYYY-MM-DD},#H{16 hex uppercase},#H{128 hex uppercase}
```

| Field | Description |
|---|---|
| `serial` | Device serial number (ASCII, same token as field 3 of `*IDN?`) |
| `hw_version` | Hardware revision string (same token as field 5 of `*IDN?`) |
| `YYYY-MM-DD` | Manufacturing / attestation date (ISO 8601 calendar date) |
| `#H…` (16 hex) | 8-byte RP2040 flash unique ID |
| `#H…` (128 hex) | 64-byte Ed25519 signature over **`{serial},{hw_version},{YYYY-MM-DD}`** (UTF-8/ASCII, no pre-hash) |

Example (truncated):

```
550e8400,A.1,2026-06-27,#H5555555555555555,#H55…55
```

Hosts verify the signature with any public key listed in the root-signed HW manifest
(`PUBLIC_KEY_HWX` in `protov-nvm`). Firmware revision is intentionally omitted; use `*IDN?`
for the full five-field identity string.

Both identification queries are non-mutations and remain available during FWUP update mode.

Host tools may verify `SYST:IDAT?` responses with
`protov_nvm::verify_serial_attestation(serial, hw_version, (year, month, day), &signature_bytes)`
after parsing the comma-separated fields (or build the message with
`protov_nvm::encode_attestation_message`).

### Measurement

| Command | Type |
|---|---|
| `MEAS:VOLT? CH1` | Query measured voltage on CH1 |
| `MEAS:VOLT? CH2` | Query measured voltage on CH2 |
| `MEAS:CURR? CH1` | Query measured current |
| `MEAS:CURR? CH2` | Query measured current |
| `MEAS:POW? CH1` | Query measured power |
| `MEAS:POW? CH2` | Query measured power |

Format: `MEAS:<KIND>? <CHANNEL>` where `<KIND>` is `VOLT`, `CURR`, or `POW`, and `<CHANNEL>` is `CH1` or `CH2`. A single space separates the `?` from the channel token.

### Channel setpoints and appearance

**Queries** — `CHn:<PARAM>?` (no trailing channel token):

| Command | Parameter |
|---|---|
| `CH1:VOLT?` / `CH2:VOLT?` | Voltage setpoint |
| `CH1:CURR?` / `CH2:CURR?` | Current limit |
| `CH1:OVP?` / `CH2:OVP?` | Over-voltage protection |
| `CH1:OCP?` / `CH2:OCP?` | Over-current protection |
| `CH1:COLR?` / `CH2:COLR?` | RGB color (`R,G,B`) |
| `CH1:MODE?` / `CH2:MODE?` | Channel mode |

**Sets** — two space-separated tokens: `CHn:<PARAM> <value>`

| Command | Example |
|---|---|
| `CH1:VOLT <float>` | `CH1:VOLT 5.0` |
| `CH1:CURR <float>` | `CH1:CURR 2.5` |
| `CH1:OVP <float>` | `CH1:OVP 5.5` |
| `CH1:OCP <float>` | `CH1:OCP 3.0` |

**Color set** — `CHn:COLR R,G,B`:

```
CH1:COLR 234,67,53
CH2:COLR 66,133,244
```

### Output enable

| Command | Type | Format |
|---|---|---|
| `OUTP CH1,ON` | Mutation | Comma between channel and state |
| `OUTP CH1,OFF` | Mutation | |
| `OUTP CH2,ON` | Mutation | |
| `OUTP CH2,OFF` | Mutation | |
| `OUTP? CH1` | Query | Space after `?` |
| `OUTP? CH2` | Query | |
| `OUTP:RESET:PROT` | Mutation | Clear protection, all channels |
| `OUTP:RESET:PROT CH1` | Mutation | Clear protection, one channel |
| `OUTP:RESET:PROT CH2` | Mutation | |

### Brightness

| Command | Type |
|---|---|
| `LCD:BRIG?` | Query LCD backlight `0`–`255` |
| `LCD:BRIG <n>` | Set LCD backlight |
| `LED:BRIG?` | Query LED brightness `0`–`255` |
| `LED:BRIG <n>` | Set LED brightness |

### Telemetry and diagnostics

| Command | Type |
|---|---|
| `TELEM?` | Aggregated telemetry snapshot |
| `TEMP? CHA` | Temperature, channel A |
| `TEMP? CHB` | Temperature, channel B |
| `TEMP? MCU` | MCU temperature |
| `INP?` | Input source (PD / adapter) |
| `DIAG?` | Diagnostic summary |
| `INA226:REG? CHA` | INA226 register dump, rail A |
| `INA226:REG? CHB` | INA226 register dump, rail B |
| `TPS55289:REG? CHA` | TPS55289 register dump, rail A |
| `TPS55289:REG? CHB` | TPS55289 register dump, rail B |

**Informal aliases** (same parsed command as the formal register queries):

| Alias | Equivalent |
|---|---|
| `INA226 DUMP CHA` | `INA226:REG? CHA` |
| `INA226 DUMP CHB` | `INA226:REG? CHB` |
| `TPS55289 DUMP CHA` | `TPS55289:REG? CHA` |
| `TPS55289 DUMP CHB` | `TPS55289:REG? CHB` |

Note: informal forms use `A` / `B` after the `CH` prefix, not `CHA` / `CHB`.

### Firmware update (FWUP)

Constants (default; enable `limits` feature to align with `protov-nvm`):

| Constant | Value |
|---|---|
| `FWUP_MAX_IMAGE_SIZE` | 819 200 bytes (800 KiB) |
| `FWUP_PAGE_SIZE` | 4096 bytes |
| `FWUP_MAX_BLOCK_LEN` | 4096 bytes |
| `FWUP_SIGNATURE_LEN` | 64 bytes |

| Command | Type | Wire form |
|---|---|---|
| `SYST:FWUP:STAT?` | Query | Session phase string (see below) |
| `SYST:FWUP:STAR <size>` | Mutation | Begin update; `<size>` = total image bytes |
| `SYST:FWUP:DATA …` | Mutation | Binary data line; see [FWUP DATA](#fwup-data) |
| `SYST:FWUP:APPL …` | Mutation | Apply signature; see [FWUP APPL](#fwup-appl) |
| `SYST:FWUP:ABOR` | Mutation | Abort session |

**Typical host sequence**

```
SYST:FWUP:STAR <image_size>     → OK or silent
SYST:FWUP:DATA #Nd<payload>     → OK (repeat)
SYST:FWUP:APPL #H<hex128>       → OK
SYST:FWUP:STAT?                 → until VERIFIED / FLASHING
```

#### FWUP STAT responses

| Value | Meaning |
|---|---|
| `IDLE` | No active session |
| `PREPARE,<total>` | Erasing / preparing flash |
| `RECV,<received>/<total>` | Receiving image bytes |
| `READY,<total>` | Image complete, awaiting signature |
| `ERROR` | Session failed |
| `VERIFIED,<total>` | Signature OK (device-specific follow-up) |
| `FLASHING` | Bootloader flashing (device-specific) |

#### FWUP DATA

ASCII prefix followed by a definite-length block and newline:

```
SYST:FWUP:DATA #44096<4096 bytes of payload>\n
```

The parser recognizes any line starting with `SYST:FWUP:DATA`; the `#Nd` header and raw payload are assembled by the transport layer. Valid payload length: `1`–`FWUP_MAX_BLOCK_LEN`.

#### FWUP APPL

```
SYST:FWUP:APPL #H<128 hex digits>\n
```

The hex block decodes to exactly **64 bytes** (Ed25519 signature). Optional `#H` prefix on the hex string is accepted by `decode_hex_block`.

## Binary blocks

ProtoV uses two IEEE 488.2 block styles.

### Definite-length decimal (`#Nd`)

```
#<N><d…d><payload>
```

- `<N>` — one ASCII digit `1`–`9`: count of length digits that follow.
- `<d…d>` — decimal length of payload in bytes.
- `<payload>` — raw bytes immediately after the length field.

Examples:

| Header | Payload length |
|---|---|
| `#5128` | 128 |
| `#44096` | 4096 |

`parse_definite_block_at` returns `(header_byte_len, payload_byte_len)`.

### Definite-length hex (`#H…`)

Hex digits only, even count, max 256 hex chars (128 bytes). Used for the FWUP signature. A leading `#H` may be present or omitted in the hex argument.

## Response model

`protov-scpi` defines how responses are represented in firmware; typical bus behavior:

| Command class | Bus line |
|---|---|
| Query (`…?`) | One line of ASCII text |
| Mutation | **Silent** (no line), or `OK` for FWUP handshakes |
| `*RST`, channel sets, `OUTP`, etc. | Silent; check `SYST:ERR?` on failure |

FWUP mutations (`STAR`, `DATA`, `APPL`, `ABOR`) may reply with `OK` or an empty line; host clients accept either.

### Errors

`SYST:ERR?` returns a single line:

```
<code>,"<message>"
```

Example: `0,"No error"`. Negative codes indicate faults; the queue is FIFO on the device.

## Session policy

Policy functions classify parsed commands for update mode and standby gating (enforced in `protov-core`, rules defined here).

### Mutations vs queries

**Queries** (not mutations): `*IDN?`, all `MEAS:?`, all `CHn:*?`, `OUTP?`, `LCD:BRIG?`, `LED:BRIG?`, `SYST:ERR?`, `SYST:VERS?`, `TELEM?`, `TEMP?`, `INP?`, `DIAG?`, `INA226:REG?`, `TPS55289:REG?`, `SYST:FWUP:STAT?`, and **Unknown** commands.

**Mutations** (everything else): includes `*RST`, `*SAV`/`*RCL`/`*DEL`, channel sets, `OUTP`, brightness sets, `SYST:LOC`/`SYST:REM`, `SYST:FWUP:STAR`, etc.

Mutations require **Standby** on the device unless in FWUP update mode.

### Update mode whitelist

When the device is in FWUP update mode, only these commands are accepted:

- `*IDN?`
- `SYST:ERR?`
- `SYST:VERS?`
- `SYST:FWUP:STAT?`
- `SYST:FWUP:DATA`
- `SYST:FWUP:ABOR`
- `SYST:FWUP:APPL`

`SYST:FWUP:STAR` starts update mode from normal operation (not whitelisted inside update mode).

### Active session requirement

`SYST:FWUP:DATA` and `SYST:FWUP:APPL` require an active FWUP session (after successful `SYST:FWUP:STAR`) when not already in update mode.

## Unknown commands

If no parser matches, the line is classified as **Unknown**: up to the first 64 bytes of the normalized command are retained. Unknown commands are treated as **non-mutations** for policy purposes; the device responds with an error via `SYST:ERR?` rather than a bus line.

## Host encoding

With the `std` feature, `encode_command_line`, `encode_fwup_data_line`, and `encode_fwup_appl_line` build wire lines from `ScpiCommand` values. **The parser in this document is authoritative** for what the device accepts; some encoder paths use alternate spellings (e.g. `SYST:BRIG:LCD` vs `LCD:BRIG`) and must not be used when talking to ProtoV firmware.

## Related crates

| Crate | Role |
|---|---|
| `protov-scpi` | Parse, encode, block math, policy, host `ScpiClient` / WASM |
| `protov-core` | Command semantics, error queue, FWUP state machine |
| `protov-hal` | USB CDC transport, FWUP payload reassembly, flash backend |

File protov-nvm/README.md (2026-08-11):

# protov-nvm

Non-volatile memory partition map and linker scripts for ProtoV.
- **2 MiB XIP flash**: W25Q16

Three hand-maintained copies of the same layout:

| File | Purpose |
|---|---|
| `linker/memory-bootloader.x` | Full linker script for feature `bootloader` |
| `linker/memory-application.x` | Full linker script for feature `application` |
| `src/layout.rs` | Rust `const`s for compile-time and host tests |

`build.rs` copies the chosen `.x` file to `OUT_DIR/memory.x`.

## Flash layout

The application and bootloader layouts are based on Embassy's RP2040
[application](https://github.com/embassy-rs/embassy/blob/main/examples/boot/application/rp/memory.x)
and
[bootloader](https://github.com/embassy-rs/embassy/blob/main/examples/boot/bootloader/rp/memory.x)
examples.

| Region / symbols | Purpose |
| --- | --- |
| `BOOT2` | RP2040 second-stage boot code at the beginning of external flash. |
| Bootloader `FLASH` | The ProtoV bootloader image. This region exists only as executable `FLASH` in the bootloader linker script. |
| `BOOTLOADER_STATE` / `__bootloader_state_*` | Persistent [Embassy Boot](https://docs.rs/embassy-boot-rp/0.10.0/embassy_boot_rp/) update state. It records swap progress so update status is preserved and recovery can continue after power loss. |
| `ACTIVE` / application `FLASH` / `__bootloader_active_*` | The current application firmware image. The bootloader calls this region `ACTIVE`; the application links itself into the same addresses as `FLASH`. |
| `DFU` / `__bootloader_dfu_*` | Staging area for a new device firmware image before the bootloader copies or swaps it into `ACTIVE`. It is one erase page larger than the active image as required by the update algorithm. |
| `RESERVED` / `__reserved_*` | Currently unallocated space reserved for user-defined future features. ProtoV product features must not consume it. |
| `CONFIG` / `__config_*` | Space reserved for persistent user configuration support to be added in a future release. |
| `FACTORY` / `__factory_*` | Factory-programmed state, including serial identity, hardware revision, manufacturing date, flash identity, and attestation data. |
| `RAM` | RP2040 runtime memory; it is not part of persistent flash storage. |

> [!NOTE]
> The `RESERVED` partition is set aside for user applications and custom data.
> ProtoV product features must not allocate or depend on this region.

If a contribution requires a new NVM allocation, open an issue or discussion
before changing the layout. Partition changes can break bootloader and software
DFU compatibility and therefore require a major version increment. See the
[contribution guidelines](../CONTRIBUTING.md#breaking-changes-2xx).

## Keeping the layout in sync

Update all three files together. Run `just test` (here) or `just nvm::test` (repo root) after changes.

The only intentional difference between the two `.x` files: **`FLASH`** is the bootloader slot in one, the ACTIVE slot in the other. Symbol block is duplicated; `__bootloader_active_*` uses `ACTIVE` (bootloader) or `FLASH` (application).

## Features

| Feature | Linker input |
|---|---|
| `bootloader` | `linker/memory-bootloader.x` |
| `application` | `linker/memory-application.x` |

## Usage

```toml
# Bootloader
protov-nvm = { path = "../protov-nvm", features = ["bootloader"] }

# Application
protov-nvm = { path = "../protov-nvm", features = ["application"] }
```

```rust
// firmware build.rs
fn main() {
    let nvm = std::env::var("DEP_PROTOV_NVM_OUT_DIR").unwrap();
    println!("cargo:rustc-link-search={nvm}");
    println!("cargo:rustc-link-arg-bins=--nmagic");
    println!("cargo:rustc-link-arg-bins=-Tlink.x");
}
```

```bash
just test                  # from protov-nvm/
just nvm::test             # from repo root
just nvm::build-bootloader
just nvm::build-application
```

## Factory sector (`FACTORY`, 4 KiB @ `0x101FF000`)

Manufacturing identity is stored at the start of the factory partition:

| Field | Size | Notes |
|---|---|---|
| Magic | 4 | `PFAC` |
| Version | 1 | `1` |
| HW rev len / serial len | 2 | ASCII byte counts |
| Date | 4 | `year` (u16 LE), `month`, `day`, pad |
| HW revision | 8 | null-padded ASCII |
| Serial | 16 | null-padded ASCII |
| Signature | 64 | Ed25519 over serial bytes |

256 bytes are programmed (padded with `0xFF`); the rest of the 4 KiB sector is erased.

Rust API: [`factory`](src/factory.rs). Application firmware loads this at boot via
`protov_core::config::init_from_factory_flash()`.

To program a unit at manufacturing time, build or build-and-flash with the
`factory-program` feature and compile-time identity env vars:

| Variable | Description |
| --- | --- |
| `SERIAL_NUMBER` | Device serial (ASCII, max 16 chars) |
| `HARDWARE_REV` | Hardware revision (e.g. `A.1`) |
| `FACTORY_YEAR` / `FACTORY_MONTH` / `FACTORY_DAY` | Manufacturing date |

Signing — provide **one** of:

| Option | Variables |
| --- | --- |
| Precomputed signature | `SIGNATURE` — 128 hex digits (64-byte Ed25519) |
| HW key signing | `HW_PRIVATE_KEY` + `HW_PUBLIC_KEY` — `.pem` paths or inline PEM; `SIGNATURE` is derived by the recipe |

The signed payload is `{serial},{hw_revision},{YYYY-MM-DD}`. The bash helper
`encode_attestation_message` in [`scripts/sign-helpers.sh`](../scripts/sign-helpers.sh)
must stay in sync with [`encode_attestation_message`](src/attestation.rs) in this
crate. When HW keys are supplied, `just factory-run` / `just factory-build` sign
with OpenSSL Ed25519 (`-rawin`, no pre-hash) and verify before invoking Cargo.

```bash
SERIAL_NUMBER=550e8400 HARDWARE_REV=A.1 \
  FACTORY_YEAR=2026 FACTORY_MONTH=6 FACTORY_DAY=27 \
  HW_PRIVATE_KEY=path/to/protov_private_HW0.pem \
  HW_PUBLIC_KEY=path/to/protov_public_HW0.pem \
  just factory-run
```

See repo-root `just factory-run` / `just factory-build`.

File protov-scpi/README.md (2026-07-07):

# protov-scpi

Centralized ProtoV SCPI wire protocol: parse, encode, IEEE `#Nd` / `#H` blocks, update-mode policy, and optional host client.

## Features

| Feature | Description |
|---|---|
| *(default)* | `no_std` codec (parse, block, policy, types) |
| `std` | `ScpiClient` + `Transport` trait |
| `limits` | FWUP constants from `protov-nvm` |
| `wasm` | `WasmScpiClient` for browsers (Web Serial via JS transport) |

Full wire-format reference: **[PROTOCOL.md](PROTOCOL.md)** (derived from `parse.rs`).

## Rust usage

```rust
use protov_scpi::{parse_command, ScpiCommand};

let cmd = parse_command("*IDN?").unwrap();
assert_eq!(cmd, ScpiCommand::IdnQuery);
```

Host client (enable `std`):

```rust
use protov_scpi::{IoTransport, ScpiClient};

let mut client = ScpiClient::new(IoTransport::new(&mut port));
client.query("*IDN?")?;
```

## WASM / Web Serial

Build (stable Rust; no wasm-pack):

```bash
just scpi-wasm-build
```

Output: `dist/wasm-scpi/` (`protov_scpi.js`, `protov_scpi_bg.wasm`, `package.json`).

On first run, installs `wasm-bindgen-cli` 0.2.126 if missing (matches workspace lockfile).

### Browser usage

Serve the repo root (or copy `dist/wasm-scpi/` into your app) and wire Web Serial into the transport callbacks:

```javascript
import init, { WasmScpiClient } from "/dist/wasm-scpi/protov_scpi.js";

await init();

const port = await navigator.serial.requestPort();
await port.open({ baudRate: 115200 });
const reader = port.readable.getReader();
const writer = port.writable.getWriter();
let lineBuf = "";

async function readLine(timeoutMs) {
  const deadline = Date.now() + timeoutMs;
  while (Date.now() < deadline) {
    if (lineBuf.includes("\n")) {
      const i = lineBuf.indexOf("\n");
      const line = lineBuf.slice(0, i).trim();
      lineBuf = lineBuf.slice(i + 1);
      return line;
    }
    const { value, done } = await reader.read();
    if (done) break;
    lineBuf += new TextDecoder().decode(value);
  }
  return null; // timeout
}

const client = new WasmScpiClient(
  (bytes) => writer.write(bytes),
  (timeoutMs) => readLine(timeoutMs),
  30000
);

console.log(client.query("*IDN?"));
```

`readLine` must resolve with a full line or `null` on timeout. `write` receives a `Uint8Array` command payload.

## Tests

```bash
just test-scpi
# or: cargo test -p protov-scpi --target $(rustc -vV | sed -n 's/host: //p') --features std
```

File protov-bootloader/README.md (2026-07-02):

# protov-bootloader

RP2040 **embassy-boot** bootloader for ProtoV, based on [Embassy's RP example](https://github.com/embassy-rs/embassy/tree/main/examples/boot/bootloader/rp).

Flash layout comes from [`protov-nvm`](../protov-nvm) (`linker/memory-bootloader.x`, `FLASH_SIZE`).

## Build / flash

```bash
just build                 # from protov-bootloader/
just bootloader::build       # from repo root
just bootloader::flash       # probe-rs via .cargo/config.toml
just bootloader::pkg         # target/protov-bootloader.uf2
```

Optional defmt:

```bash
cargo build -p protov-bootloader --release --features defmt
```

## Behaviour

On boot: init flash + watchdog, read ACTIVE/DFU/STATE partitions from linker symbols, run embassy-boot swap logic if needed, then jump to the application in ACTIVE (`0x10007000`).

The bootloader itself links into the ~24 KiB slot at `0x10000100`.

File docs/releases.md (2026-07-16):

# Release builds

Create a release bundle with a version number that does not include a `v`
prefix:

```sh
just release-bundle 1.7.3
```

The command builds A.0, A.1, and A.2 firmware and writes the artifacts,
manifest, checksums, and archive under `dist/`.

Release packaging requires `arm-none-eabi-objcopy` and `elf2uf2-rs`.

## Signing

> [!IMPORTANT]
> Signing is not required for development builds flashed through USB BOOTSEL or
> SWD. A matching firmware signature is required only when an image is
> delivered through [DFU over SCPI](../protov-scpi/PROTOCOL.md#firmware-update-fwup).

Set `PRIVATE_KEY` and `PUBLIC_KEY` to include signed firmware in a local
release:

```sh
PRIVATE_KEY=... PUBLIC_KEY=... just release-bundle 1.7.3
```

To sign the current default build only:

```sh
just build
PRIVATE_KEY=... PUBLIC_KEY=... just sign-firmware
```

The [`protov-nvm` documentation](../protov-nvm/README.md) describes the flash
layout, and the [signing-key documentation](../protov-nvm/keys/README.md)
describes the Ed25519 key files, root-signed CI key manifest, verification
format, rotation, and revocation.

> [!CAUTION]
> Never commit private signing keys. Pull requests that add or modify trusted
> public keys will be rejected. Changes to the firmware signing or verification
> workflow will be thoroughly reviewed to ensure backwards compatibility.

### Verification path

The device handles SCPI DFU in `protov-hal`. During
[`FirmwareCtx::dfu_verify_apply`](../protov-hal/src/hal/firmware.rs#L143-L171),
it first verifies the embedded CI key manifest and then calls
[`verify_and_mark_updated(key, &signature, len)`](../protov-hal/src/hal/firmware.rs#L153-L167)
for each authorized release key. The update is marked ready only when one of
those keys verifies the supplied image signature. The
[bootloader](../protov-bootloader/README.md#behaviour) applies that verified
image on reboot.

[ProtoV App](https://protov.app) and the
[`protov_app` repository](https://github.com/flakeblade/protov_app) use signed
firmware artifacts for web-based DFU. These artifacts are pulled directly from the CI release of this repository. The app submits the image and signature;
the device checks them against its embedded trusted keys before accepting the
update.

### Custom keys and unsigned firmware

The recommended way to distribute custom firmware over SCPI DFU is to maintain
your own trust chain:

1. Follow the [documented raw-key and manifest format](../protov-nvm/keys/README.md#files).
2. Replace the root key and CI manifest in `protov-nvm`, then sign the manifest
   with your own root private key. Adding a public key alone is insufficient:
   the CI manifest must match the root embedded in your firmware.
3. Build and install that initial custom firmware through
   [USB BOOTSEL](flashing.md#option-2-usb-bootsel) or
   [SWD](flashing.md#option-3-swd-debug-probe).
4. Sign future releases with an authorized private release key and configure
   your own build of [`protov_app`](https://github.com/flakeblade/protov_app)
   to provide the matching image and signature. The existing
   `verify_and_mark_updated` path will then enforce your keys.

You may instead modify your firmware to bypass signature verification. The
stock signed-DFU path cannot install that first modified image, so it must be
loaded through [USB BOOTSEL](flashing.md#option-2-usb-bootsel) or
[SWD](flashing.md#option-3-swd-debug-probe).
Afterward, a custom DFU implementation can accept unsigned images.

> [!CAUTION]
> Disabling verification removes firmware-authenticity protection. Also,
> `verify_and_mark_updated` both verifies **and** marks the image for boot; do
> not simply delete the call without providing the required update-state
> handling. Any verifier-free firmware or update flow is used entirely at your
> own risk.

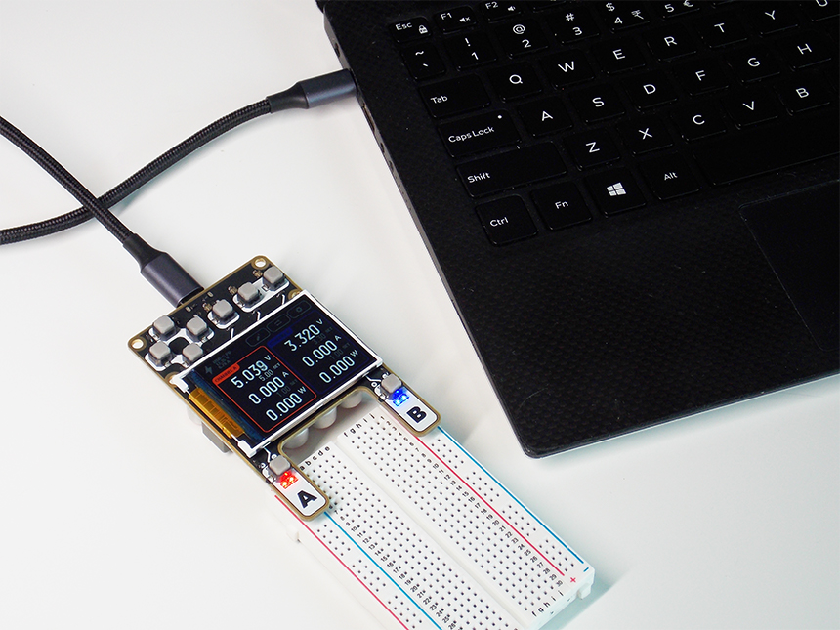
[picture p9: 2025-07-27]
docs/res/laptop.jpg

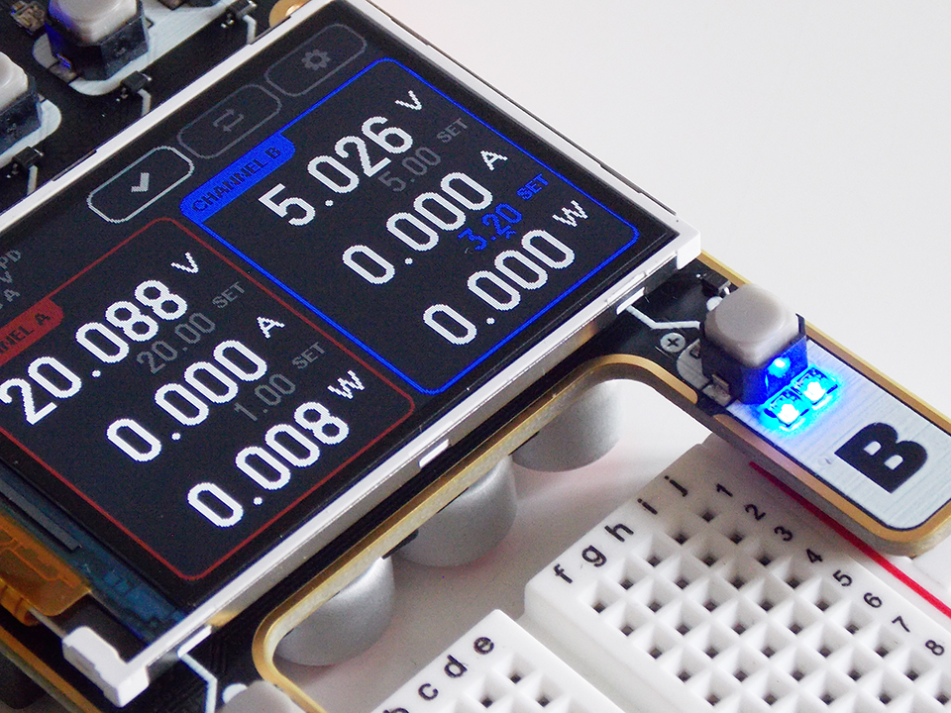
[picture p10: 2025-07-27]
docs/res/ui.jpg

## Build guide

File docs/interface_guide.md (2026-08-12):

# Interface guide

This guide walks through ProtoV MINI's on-device UI in the order you normally
encounter it. Each step links to a rendered example screen from
[`docs/res/ui/`](res/ui/) (generated from [`protov-hal-mock/states/`](../protov-hal-mock/states/)
via `just render-ui`). For a flat catalog of every render, see
[`ui-states.md`](ui-states.md).

ProtoV MINI has two **normal** operating paths:

| Path | Power | Host | Navbar (top-left) |
| --- | --- | --- | --- |
| [Standalone (PD only)](#standalone-usb-c-pd-only) | USB-C PD supply | None | Lightning icon, **USB PD** or **USB2.0**, negotiated W/V/A |
| [Computer linked](#computer-linked) | USB-C PD via OTG splitter | ProtoV App or SCPI | Link icon, **LINKED**, negotiated W/V/A |

Both paths share the same boot sequence and main-screen controls. The
[troubleshooting guide](troubleshooting.md) covers boot failures, protection
trips, and other fault screens.

## Controls

| Control | Navigation mode | Setpoint-edit mode |
| --- | --- | --- |
| **Channel A / B** | First press selects channel; second press on the selected channel enables output; third press disables output | Exits edit mode and selects the pressed channel |
| **Up / Down** | Toggle voltage vs current row for the selected channel | Increment / decrement the digit under the cursor |
| **Left / Right** | Move selection between Channel A and Channel B | Move the edit cursor across digits |
| **Enter** (pencil ✎ / check ✓) | Short press: enter setpoint edit for selected channel | Short press: confirm value and apply; toggles back to navigation |
| **Switch** (⇄) | Toggle **SET** (output setpoints) vs **LIMITS** (OVP/OCP) | Same toggle; edit mode is preserved |
| **Settings** (⚙) | Open / close settings overlay | Blocked while settings are open |

Factory default setpoints after boot: Channel A **5.00 V / 1.00 A**, Channel B
**3.30 V / 1.00 A**. Protection defaults: **20.0 V** OVP and **5.0 A** OCP per
channel ([`CH1_FACTORY` / `CH2_FACTORY`](../protov-core/src/config/channel.rs)).

---

## Boot sequence (both paths)

Applies every time power is applied. Steps advance automatically; no button
input is required during boot.

| Step | Screen | What it means |
| --- | --- | --- |
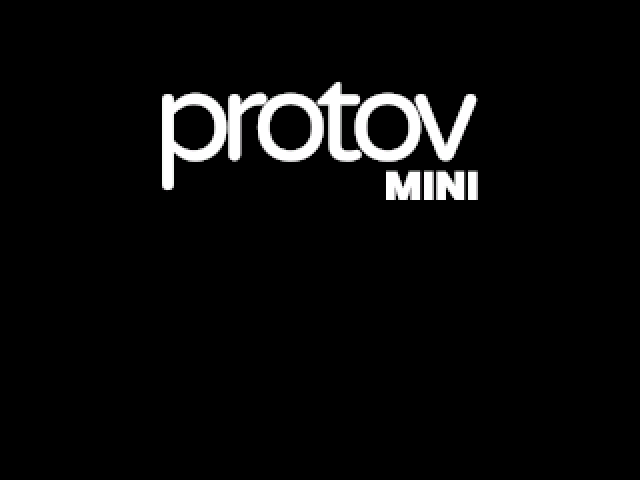
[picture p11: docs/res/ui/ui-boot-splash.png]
Boot splash
| 1 |  | Logo splash while firmware initializes |
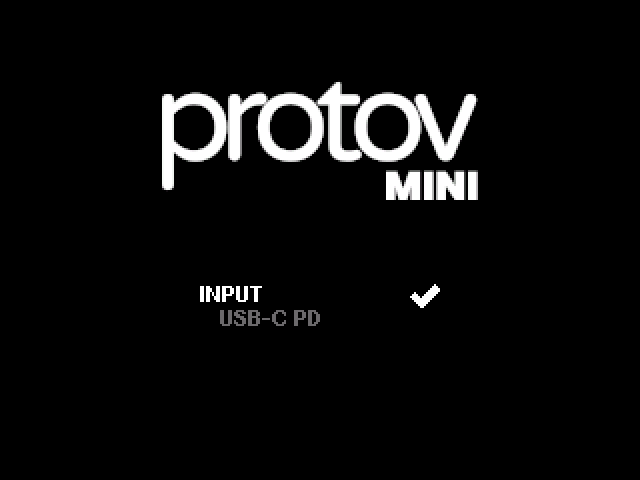
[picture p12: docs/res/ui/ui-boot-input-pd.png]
Boot input PD
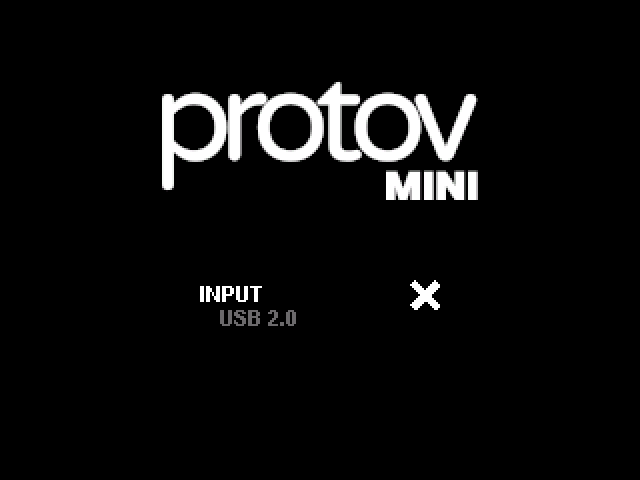
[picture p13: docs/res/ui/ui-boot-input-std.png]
Boot input standard
| 2 |  or  | **INPUT** line confirms USB-C PD (✓) or standard 5 V USB (✗ on PD row). PD example shows negotiated **9.00 V / 3.00 A** in the navbar after main UI loads |
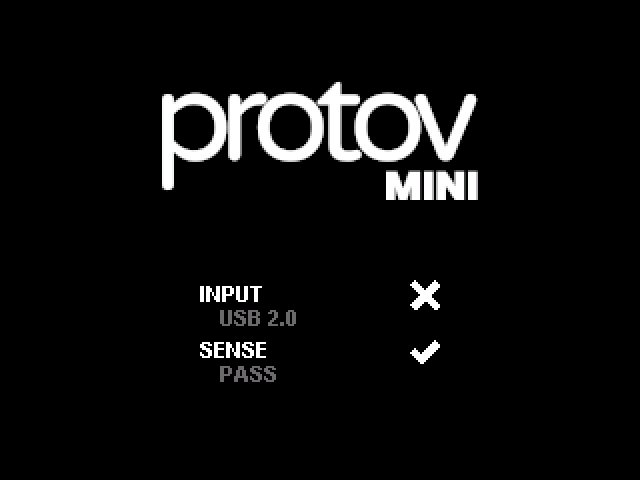
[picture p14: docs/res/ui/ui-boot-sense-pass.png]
Boot sense pass
| 3 |  | **SENSE** calibration passed |
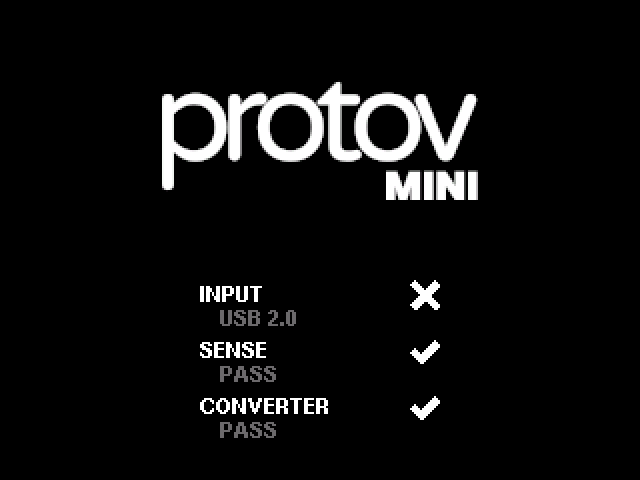
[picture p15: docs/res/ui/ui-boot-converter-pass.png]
Boot converter pass
| 4 |  | **CONVERTER** self-test passed |

After step 4 the device enters the main interface. If sense or converter shows
**FAIL**, see [Boot self-check failures](troubleshooting.md#boot-self-check-failures).

---

## Standalone (USB-C PD only)

Use this path when ProtoV MINI is powered from a USB-C PD adapter and controlled
only from the front panel. Setup steps are in [Quick start — Option
1](quick_start.md#option-1-usb-c-pd-supply-only).

### 1. Standby main screen

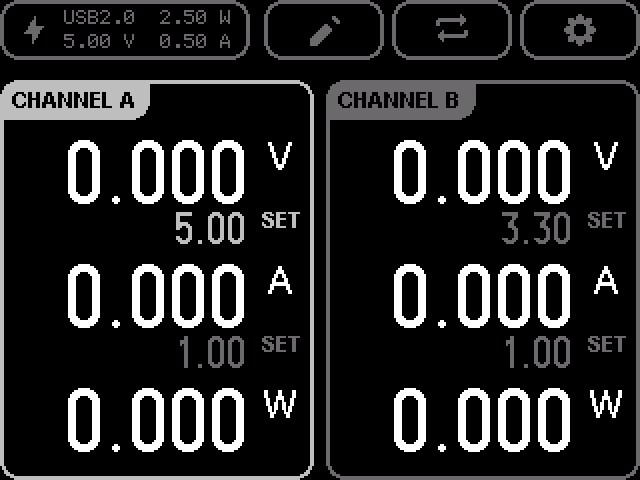
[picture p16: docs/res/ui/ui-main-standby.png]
Main standby


After boot, both outputs are off. Large readouts show **0.000**; **SET** rows
show factory setpoints. The navbar shows the negotiated input contract (example:
**USB2.0  2.50 W** and **5.00 V  0.50 A** for a 5 V / 0.5 A standard-USB
input).

**Verify:** Compare the navbar W/V/A with your supply rating. If you expected
**USB PD** but see **USB2.0**, see [Wrong power type at boot](troubleshooting.md#wrong-power-type-at-boot).

### 2. Select a channel

Press **Channel B** once (while Channel A is selected from boot).

- Channel B header highlights; output stays off.
- **Up / Down** now affect Channel B's voltage/current row selection.

Press **Left** to return selection to Channel A.

### 3. Choose voltage or current row

With a channel selected, **Up** selects the **voltage** row; **Down** selects the
**current** row. The active row is highlighted before editing.

### 4. Edit a setpoint

1. Press **Enter** → pencil icon becomes check; the selected row enters edit
   mode (red **SET** text and cursor).
2. **Left / Right** move the cursor across digits:

   | Cursor position | Example |
   | --- | --- |
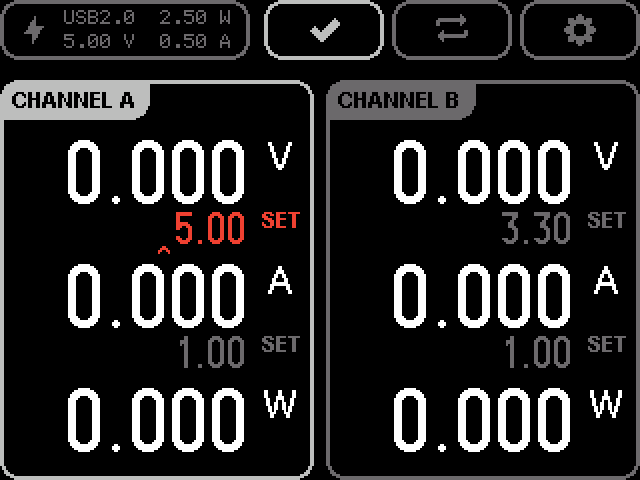
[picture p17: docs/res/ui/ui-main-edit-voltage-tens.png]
Edit voltage — tens
   | Tens |  |
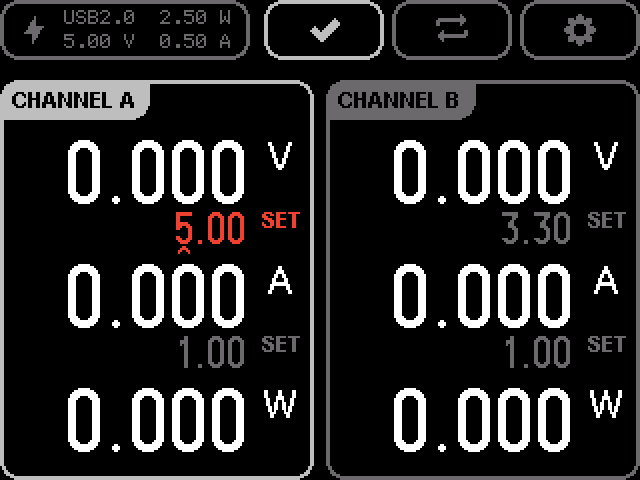
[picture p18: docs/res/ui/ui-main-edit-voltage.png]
Edit voltage — ones
   | Ones |  |
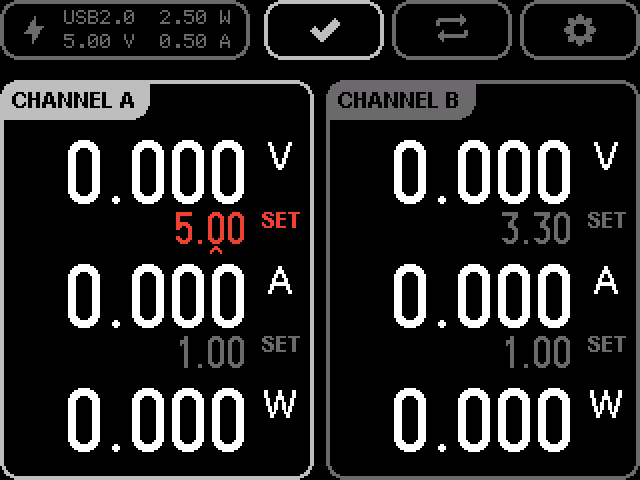
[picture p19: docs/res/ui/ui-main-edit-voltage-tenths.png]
Edit voltage — tenths
   | Tenths |  |
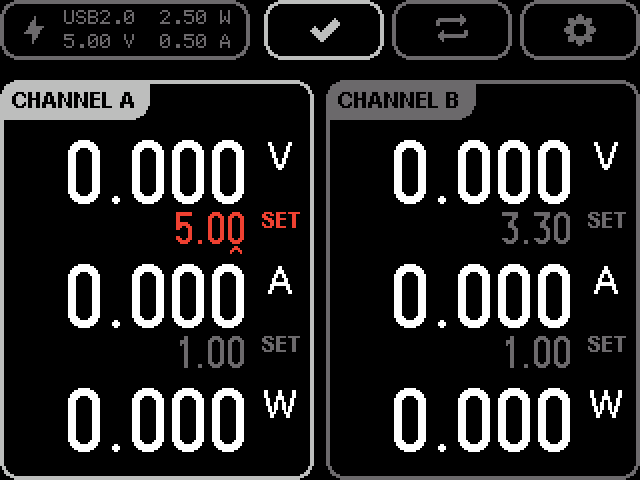
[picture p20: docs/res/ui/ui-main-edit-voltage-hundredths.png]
Edit voltage — hundredths
   | Hundredths |  |

   For the **current** row:

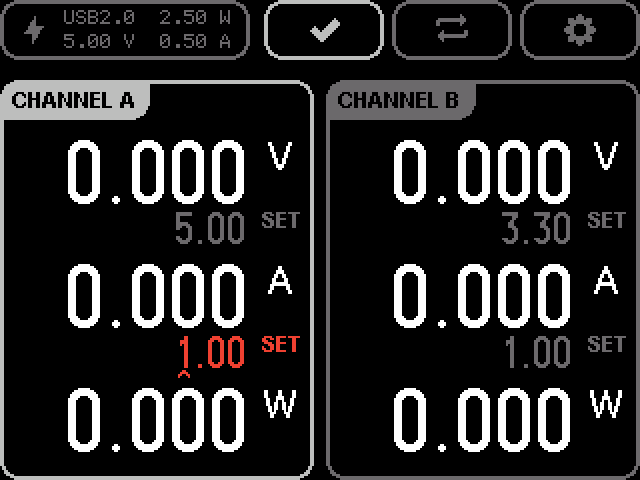
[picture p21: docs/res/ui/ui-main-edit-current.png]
Edit current
   

3. **Up / Down** increment or decrement the digit under the cursor.
4. Press **Enter** again to confirm and return to navigation mode.

Setpoint ranges: voltage **0.2–20.0 V** (10 mV steps), current **0–5.0 A** (50 mA
steps) — see [product specifications](product.md#specifications).

### 5. Enable output

1. Select the channel (**Channel A** or **Channel B** once if not already selected).
2. Press the same **channel button** again → output enables.

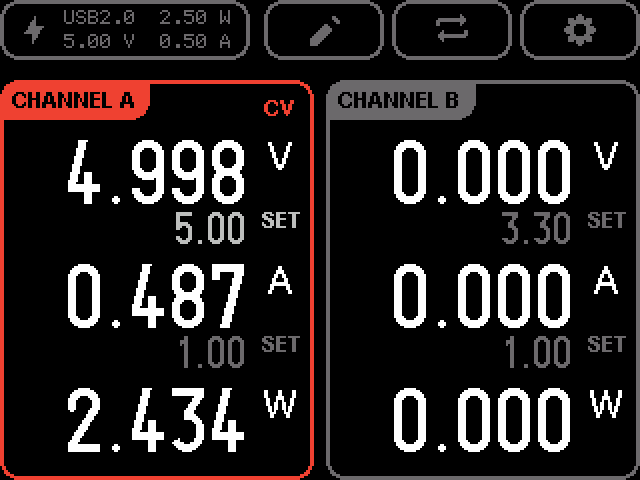
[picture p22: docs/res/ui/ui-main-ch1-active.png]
CH1 active


Large readouts show live measurements; a **CV** or **CC** chip appears when the
channel is regulating. Examples:

| Mode | Screen | When |
| --- | --- | --- |
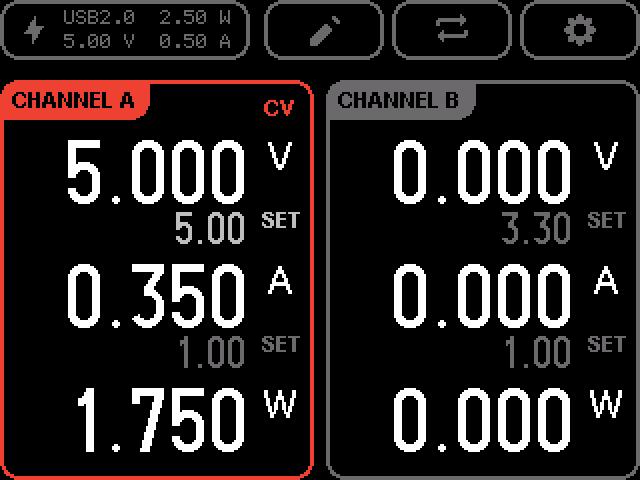
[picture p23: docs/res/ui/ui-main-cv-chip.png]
CV chip
| Constant voltage |  | Load draws less current than the limit; voltage holds at setpoint |
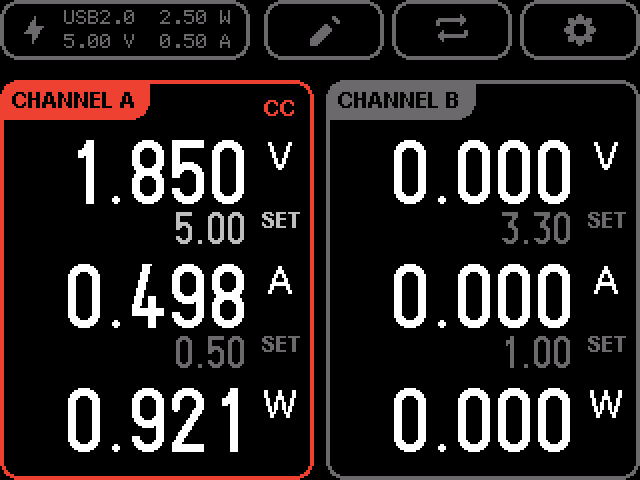
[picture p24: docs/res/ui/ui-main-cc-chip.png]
CC chip
| Constant current |  | Load demands more current than the setpoint; current limits and voltage drops |

Press the **channel button** a third time to turn output off.

### 6. Run both channels

Enable Channel A, then select and enable Channel B:

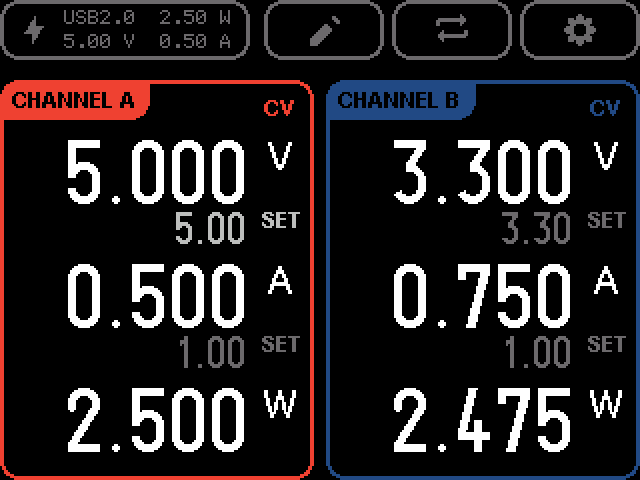
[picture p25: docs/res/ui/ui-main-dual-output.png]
Dual output


Total load must stay within the negotiated USB input power shown in the navbar.

### 7. Adjust protection limits (OVP / OCP)

1. Press **Switch** (⇄) → tags change from **SET** to **OVP** / **OCP**.

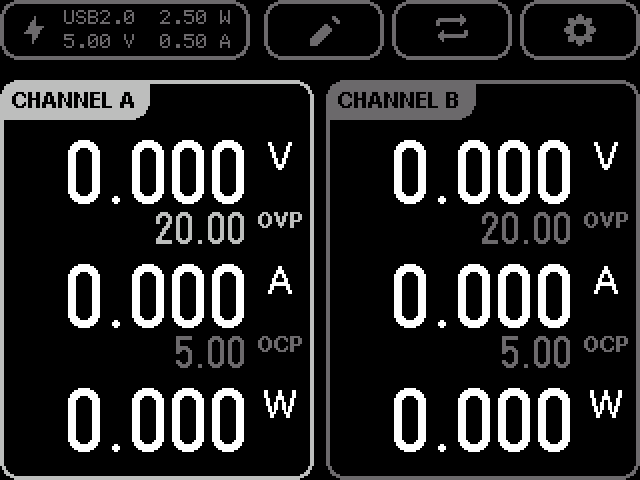
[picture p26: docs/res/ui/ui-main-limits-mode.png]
Limits mode
   

2. **Up / Down** choose voltage (OVP) or current (OCP) row.
3. **Enter** and edit with the same cursor controls as setpoints.
4. Press **Switch** again to return to **SET** mode.

Default limits are defined in [`protov-core/src/config/channel.rs`](../protov-core/src/config/channel.rs)
(`ovp`, `ocp` per channel). SCPI queries: `CH1:OVP?`, `CH1:OCP?` — see
[SCPI protocol](../protov-scpi/PROTOCOL.md#channel-queries).

### 8. Settings overlay

Press **Settings** (⚙) from the main screen:

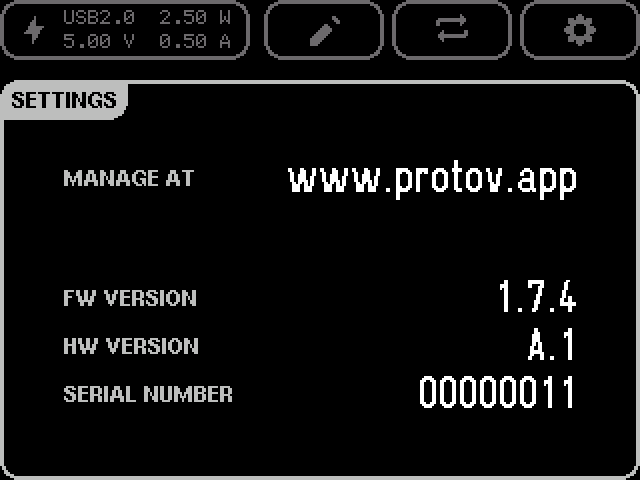
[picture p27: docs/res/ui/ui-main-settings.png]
Settings


Shows firmware version, hardware revision, and serial number. Press **Settings**
again to close. Live readouts pause while settings are open.

---

## Computer linked

Use this path when a computer is connected through a USB-C OTG splitter while
PD power is supplied. Setup is in [Quick start — Option
2](quick_start.md#option-2-usb-c-pd-supply-and-computer).

### 1. Linked navbar

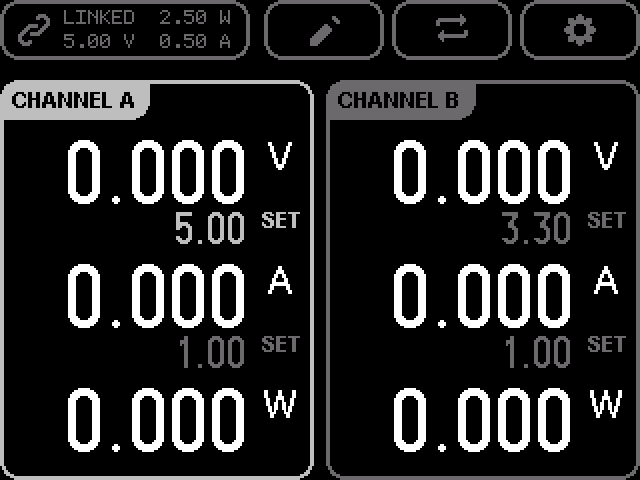
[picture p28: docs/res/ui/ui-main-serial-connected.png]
Serial connected


When the USB data link is active, the navbar shows the **link** icon and
**LINKED** instead of **USB PD** / **USB2.0**. Negotiated input W/V/A still
appear on the second line.

**Verify:** If ProtoV App cannot connect but power works, confirm **LINKED**
appears. See [Host not linked](troubleshooting.md#host-not-linked).

### 2. Remote control

With **LINKED**, [ProtoV App](https://protov.app) or SCPI can change setpoints,
outputs, and limits while the on-device UI mirrors state. Front-panel buttons
remain available unless the host holds remote lock (`SYST:REM`).

### 3. Custom channel colors

From ProtoV App or SCPI, set per-channel RGB colors (`CH1:COLR`, `CH2:COLR` in
[SCPI protocol](../protov-scpi/PROTOCOL.md#channel-configuration)):

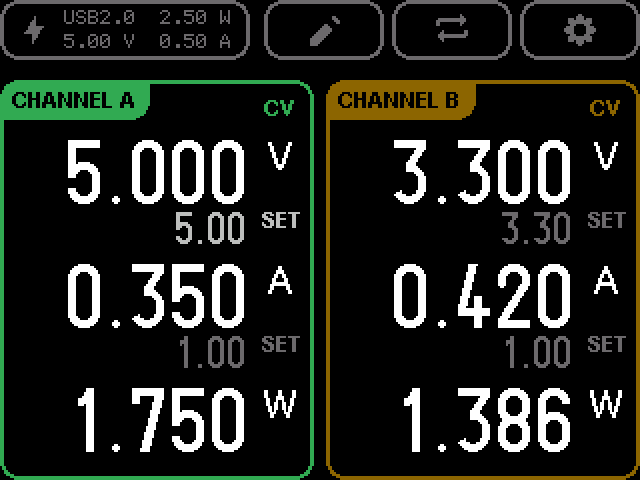
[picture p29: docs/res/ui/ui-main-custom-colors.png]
Custom colors


Example: Channel A green `52,168,83`, Channel B yellow `251,188,5`. Colors appear
on channel borders when that channel's output is enabled (or when selected with
output on). Factory defaults are red / blue
([`DEFAULT_CH1` / `DEFAULT_CH2`](../protov-core/src/config/appearance.rs)).

### 4. Same main-screen flow

Standby, setpoint edit, output enable, limits, and settings work the same as
[standalone](#standalone-usb-c-pd-only). Prefer the host for bulk changes; use
the panel for quick adjustments in the lab.

---

## Firmware update screens (host-initiated)

Firmware updates are normally started from ProtoV App or SCPI (`SYST:FWUP:STAR`).
On-device display during update:

| Phase | Screen |
| --- | --- |
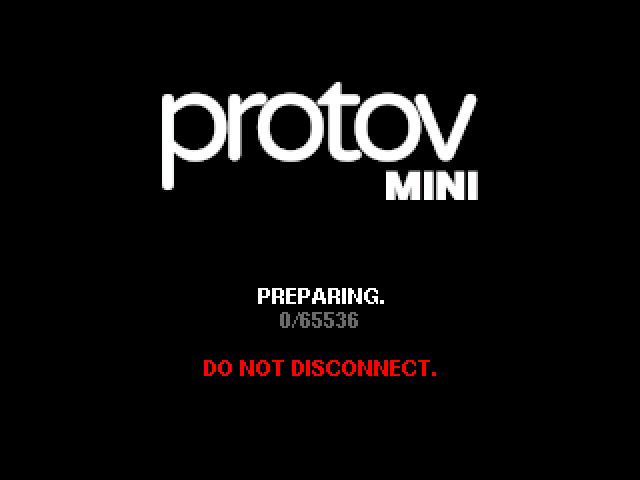
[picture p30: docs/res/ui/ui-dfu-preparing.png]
DFU preparing
| Preparing |  |
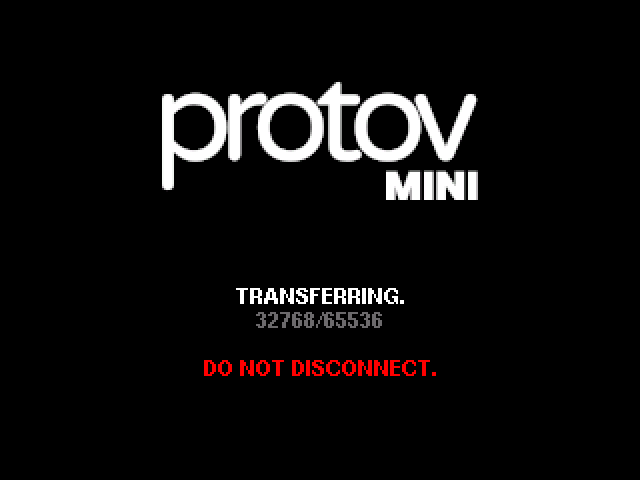
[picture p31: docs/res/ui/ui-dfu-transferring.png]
DFU transferring
| Transferring |  |
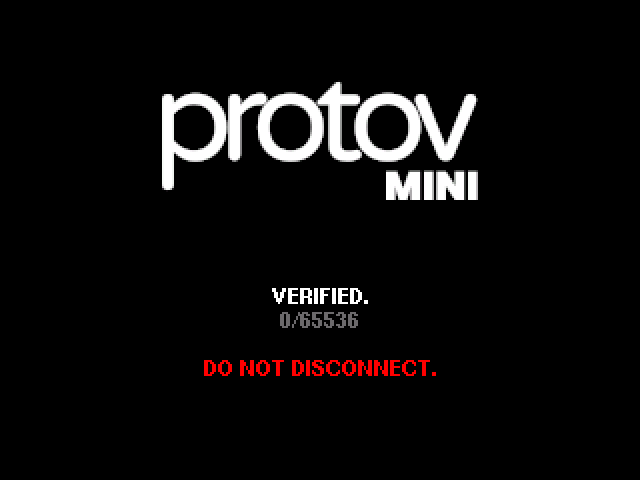
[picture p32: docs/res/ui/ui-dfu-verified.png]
DFU verified
| Verified |  |
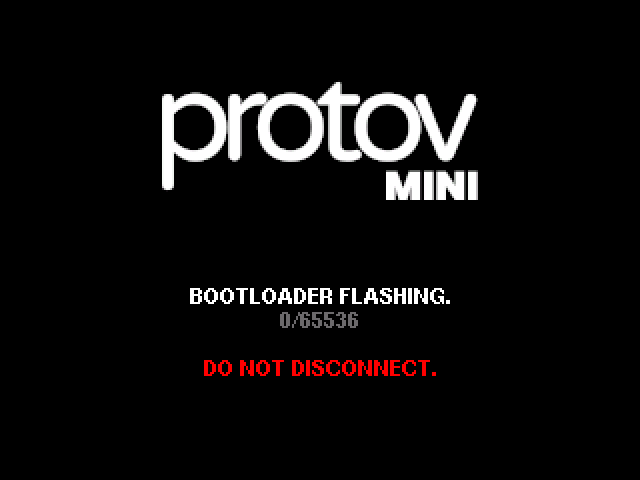
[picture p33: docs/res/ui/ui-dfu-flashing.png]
DFU flashing
| Flashing |  |

Do not disconnect power during transfer. If update fails, see
[Firmware update failed](troubleshooting.md#firmware-update-failed).

---

## Quick reference — button sequence cheat sheet

**Set Channel A to 5 V / 0.5 A and enable (from standby):**

1. Boot completes → standby.
2. **Up** (voltage row selected by default on Channel A).
3. **Enter** → edit voltage → adjust digits → **Enter** confirm.
4. **Down** → current row → **Enter** → adjust → **Enter** confirm.
5. **Channel A** → enable output.

**Adjust Channel A OVP:**

1. **Switch** → limits mode.
2. **Up** (OVP row) → **Enter** → edit → **Enter** confirm.
3. **Switch** → back to SET mode.

**Open settings:** **Settings** → read versions → **Settings** again to close.

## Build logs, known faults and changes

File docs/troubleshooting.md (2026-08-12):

# Troubleshooting

This guide covers ProtoV MINI screens that indicate a fault, a failed check, or
misconfiguration. Each section links to example renders in
[`docs/res/ui/`](res/ui/). For the normal button-by-button flow, see the
[interface guide](interface_guide.md). For wiring and supply compatibility, see
[compatibility](compatibility.md).

---

## Boot self-check failures

During power-on, the splash screen accumulates three checks. Any **FAIL** stops
normal operation until power is cycled after the underlying issue is fixed.

| Screen | Check | Typical causes |
| --- | --- | --- |
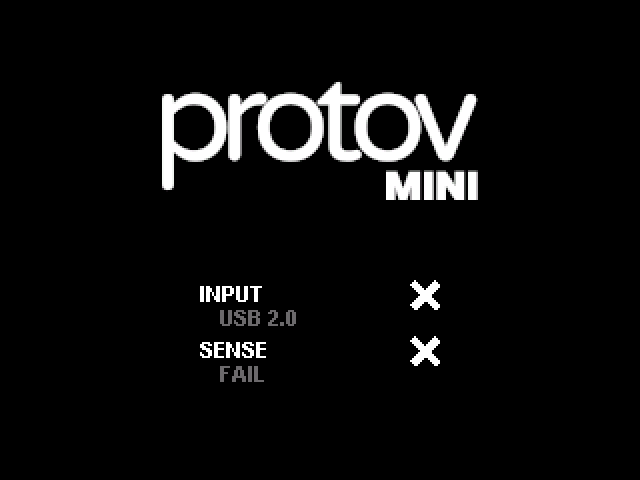
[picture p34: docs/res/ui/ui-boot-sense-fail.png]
Boot sense fail
|  | **SENSE** | Measurement path fault, hardware damage, marginal sense calibration |
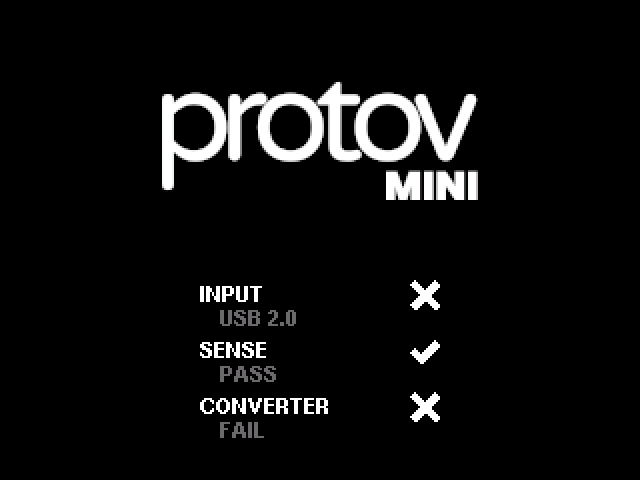
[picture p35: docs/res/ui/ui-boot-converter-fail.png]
Boot converter fail
|  | **CONVERTER** | Power-stage self-test failure, input power inadequate for test, hardware fault |

**Passing references:**

- Boot sense pass
- Boot converter pass

**What to try:**

1. Disconnect all loads from output headers.
2. Power-cycle with a known-good [USB-C PD source](compatibility.md#usb-c-power-sources)
   and CC-capable cable ([quick start](quick_start.md)).
3. If failures persist across supplies, contact support with hardware revision
   (settings overlay or `*IDN?`) and serial number.

Sense/converter results are also exposed on the SCPI telemetry context
(`sense_ok`, `converter_ok` in [`ScpiContext`](../protov-core/src/scpi/mod.rs)).

---

## Wrong power type at boot

| Screen | Meaning |
| --- | --- |
| Boot input PD | PD contract negotiated (✓ on **USB-C PD** row) |
| Boot input standard | Standard USB 5 V only (✗ on PD row) |

**Symptom:** Main UI navbar shows **USB2.0** but the supply is PD-capable, or
available output power is lower than expected.

**What to try:**

1. Use a USB-C cable with **Configuration Channel (CC)** wires — see [Quick
   start](quick_start.md#option-1-usb-c-pd-supply-only).
2. Confirm the supply and port support PD ([compatibility](compatibility.md#usb-c-power-sources)).
3. Reconnect the cable; try flipping the USB-C orientation on marginal cables.
4. With a computer link, use an OTG splitter and connect **PD first, then data,
   then the device** ([quick start — Option 2](quick_start.md#option-2-usb-c-pd-supply-and-computer)).

The navbar W/V/A lines reflect the **negotiated input contract**, not the channel
setpoints. Channel outputs cannot draw more total power than this contract allows.

---

## Host not linked

| Screen | Meaning |
| --- | --- |
| Serial connected | USB data link active — **LINKED** in navbar |

**Symptom:** ProtoV App does not list the device, or SCPI/WebSocket tools cannot
connect, while power and the front panel work.

**What to try:**

1. Confirm the display shows **LINKED** (not just **USB PD**).
2. Connect the computer to the splitter's **data** port, not the PD-only port.
3. Use a [supported browser/OS](compatibility.md#protov-app).
4. Check USB cable data lines; charge-only cables will not link.
5. Close other apps that may hold the serial port.

---

## Limits mode and protection trips

### Editing limits

Limits mode

Press **Switch** (⇄) on the main screen to edit **OVP** (over-voltage) and
**OCP** (over-current) thresholds instead of output setpoints. The edit flow
matches SET mode: **Up/Down** select row, **Enter** to edit, **Left/Right** for
cursor, **Enter** to confirm.

Limits are stored per channel. Factory defaults: **20.0 V** OVP, **5.0 A** OCP
([`CH1_FACTORY` / `CH2_FACTORY`](../protov-core/src/config/channel.rs)).

SCPI:

| Command | Purpose |
| --- | --- |
| `CH1:OVP?` / `CH2:OVP?` | Query voltage limit |
| `CH1:OCP?` / `CH2:OCP?` | Query current limit |
| `CH1:OVP 12.0` | Set OVP (example) |

See [SCPI protocol — channel configuration](../protov-scpi/PROTOCOL.md).

### Protection latched (output shut off)

When a fault is detected, the channel output disables and a fault chip latches
until cleared. Large readouts may show **0.000** while the fault tag remains.

| Fault | Screen | Typical trigger |
| --- | --- | --- |
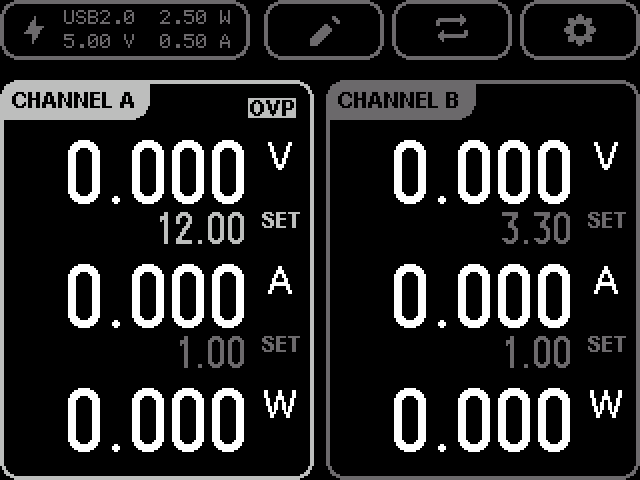
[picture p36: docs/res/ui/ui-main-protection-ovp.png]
OVP latched
| Over-voltage |  | Output or input exceeded **OVP** setting; load dump, wiring fault |
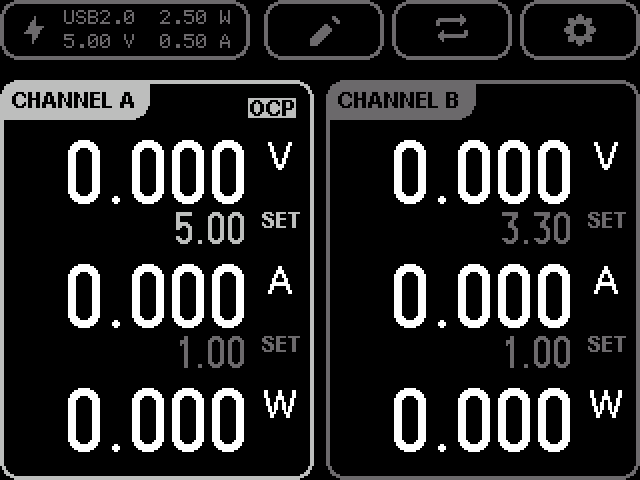
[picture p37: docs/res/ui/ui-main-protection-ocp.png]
OCP latched
| Over-current |  | Load drew more than **OCP** limit |
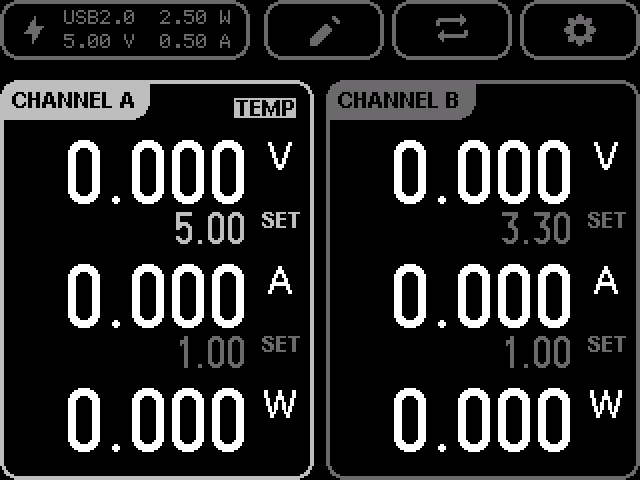
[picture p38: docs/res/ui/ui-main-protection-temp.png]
TEMP latched
| Over-temperature |  | Converter or board overheated |
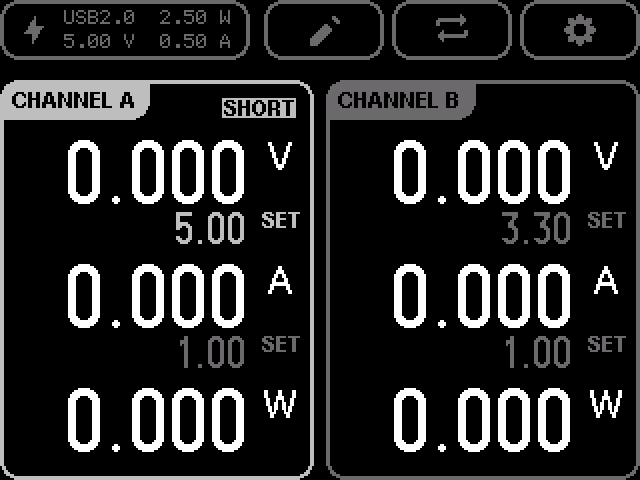
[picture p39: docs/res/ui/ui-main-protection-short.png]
SHORT latched
| Short circuit |  | Very low impedance on output |

**What to try:**

1. **Power-cycle the device** — disconnect USB power, wait a few seconds, and
   reconnect a stable supply. A reboot clears many latched protection states
   once the underlying fault is gone.
2. **Remove the fault condition** — disconnect load, fix wiring, lower setpoints
   or limits if misconfigured. For **TEMP**, allow the board to cool before and
   after the reboot; the latch may remain until the converter is below the
   over-temperature threshold again.
3. **Clear the latch** (if the fault chip persists after power-cycle):
   - From ProtoV App or SCPI: `OUTP:RESET:PROT` (all channels) or
     `OUTP:RESET:PROT CH1` / `CH2` ([SCPI protocol](../protov-scpi/PROTOCOL.md)).
   - Factory reset `*RST` clears protection but restores all settings to factory
     defaults — use with care.
4. Re-enable the channel from the front panel (**channel button**) once the
   latch is cleared and conditions are safe.

**Prevention:**

- Set OVP/OCP above expected operating points but below hardware maximums
  ([product specifications](product.md#specifications): 0–20 V, 0–5 A).
- Avoid hot-plugging heavy capacitive loads.
- Ensure adequate cooling and input power headroom in the navbar.

Query latched state: `CH1:MODE?` returns `OVP`, `OCP`, `TEMP`, `SHORT`, `CV`,
`CC`, or `OFF`.

---

## Output behaves unexpectedly (not a fault screen)

These are normal operating modes that are often mistaken for errors:

| Screen | Meaning |
| --- | --- |
| CV chip | **CV** — regulating voltage; current below limit |
| CC chip | **CC** — current at setpoint; voltage dropped to satisfy load |

If voltage is lower than the setpoint under load, the channel is in **CC**, not
failed CV. Raise the current setpoint or reduce load.

---

## Firmware update failed

| Phase | Screen |
| --- | --- |
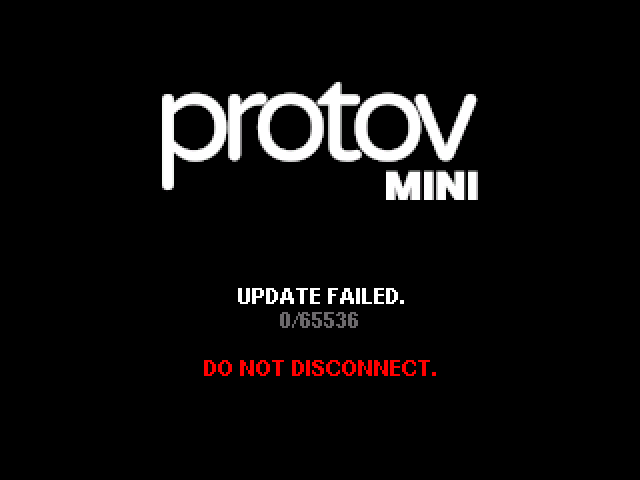
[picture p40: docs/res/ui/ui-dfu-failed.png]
DFU failed
| Failed |  |
| (success path) | [Preparing → Transferring → Verified → Flashing](interface_guide.md#firmware-update-screens-host-initiated) |

**What to try:**

After a failed upload, the **bootloader recovers automatically** — you do not
need to enter recovery mode immediately.

1. Disconnect and reconnect a **stable** USB-C PD power source (or power cycle
   through your OTG splitter if a computer is linked).
2. The display may stay **blank for up to 120 seconds** while the bootloader
   validates and restores the previous firmware image.
3. Wait for the normal boot sequence (splash → input check → sense → converter →
   main UI). Do not disconnect power during this window.
4. Once boot completes, retry the update from ProtoV App or SCPI after
   `SYST:FWUP:STAT?` reports `IDLE`. Use a signed firmware bundle from a
   [release](releases.md) matching your hardware revision.
5. If the display remains blank for **more than 120 seconds**, or the device
   does not reach the main UI, proceed with manual recovery via USB BOOTSEL or
   SWD — see [flashing](flashing.md).

---

## SCPI and settings conflicts

Protection and remote-control operations may push errors to the SCPI queue while
the front panel shows a latched fault. Example from the OVP preset:
`-221,"Settings conflict"`.

Check errors with `SYST:ERR?`. Resolve remote vs local conflicts with
`SYST:LOC` / `SYST:REM` as appropriate ([SCPI protocol](../protov-scpi/PROTOCOL.md)).

---

## When nothing works — checklist

| Check | Action |
| --- | --- |
| No display | Verify PD supply, cable CC, try another port/cable |
| Boot loops on FAIL | [Boot self-check failures](#boot-self-check-failures) |
| **USB2.0** instead of PD | [Wrong power type](#wrong-power-type-at-boot) |
| No **LINKED** | [Host not linked](#host-not-linked) |
| Output won't turn on | Protection latched? Run `OUTP:RESET:PROT` after fixing fault |
| Output low voltage | [CC mode](#output-behaves-unexpectedly-not-a-fault-screen) or input power limit in navbar |
| App settings don't stick | Host in remote mode; check `SYST:ERR?` for `-221` conflicts |

For hardware dimensions, revision identification, and design files, see
[hardware](hardware.md). For development and mock-server testing of these UI
states, see [`protov-hal-mock`](../protov-hal-mock/README.md).

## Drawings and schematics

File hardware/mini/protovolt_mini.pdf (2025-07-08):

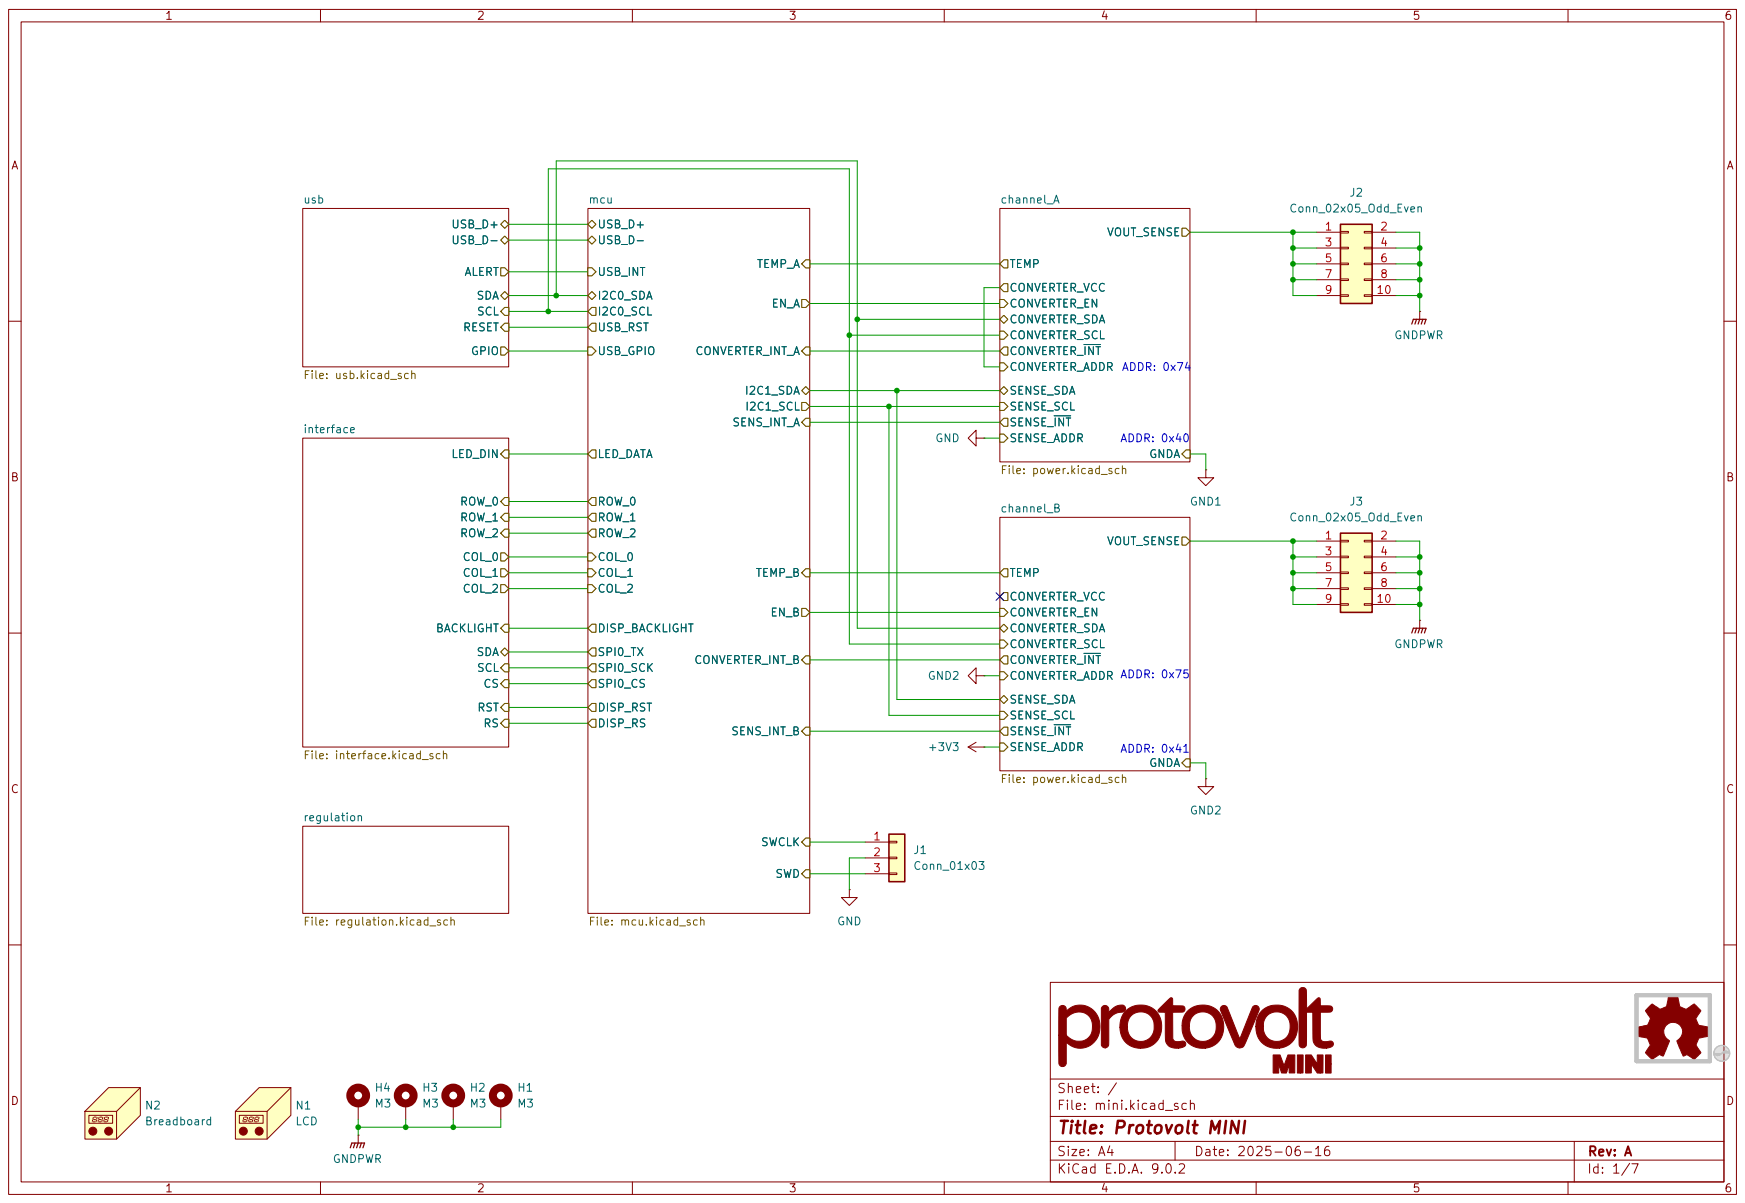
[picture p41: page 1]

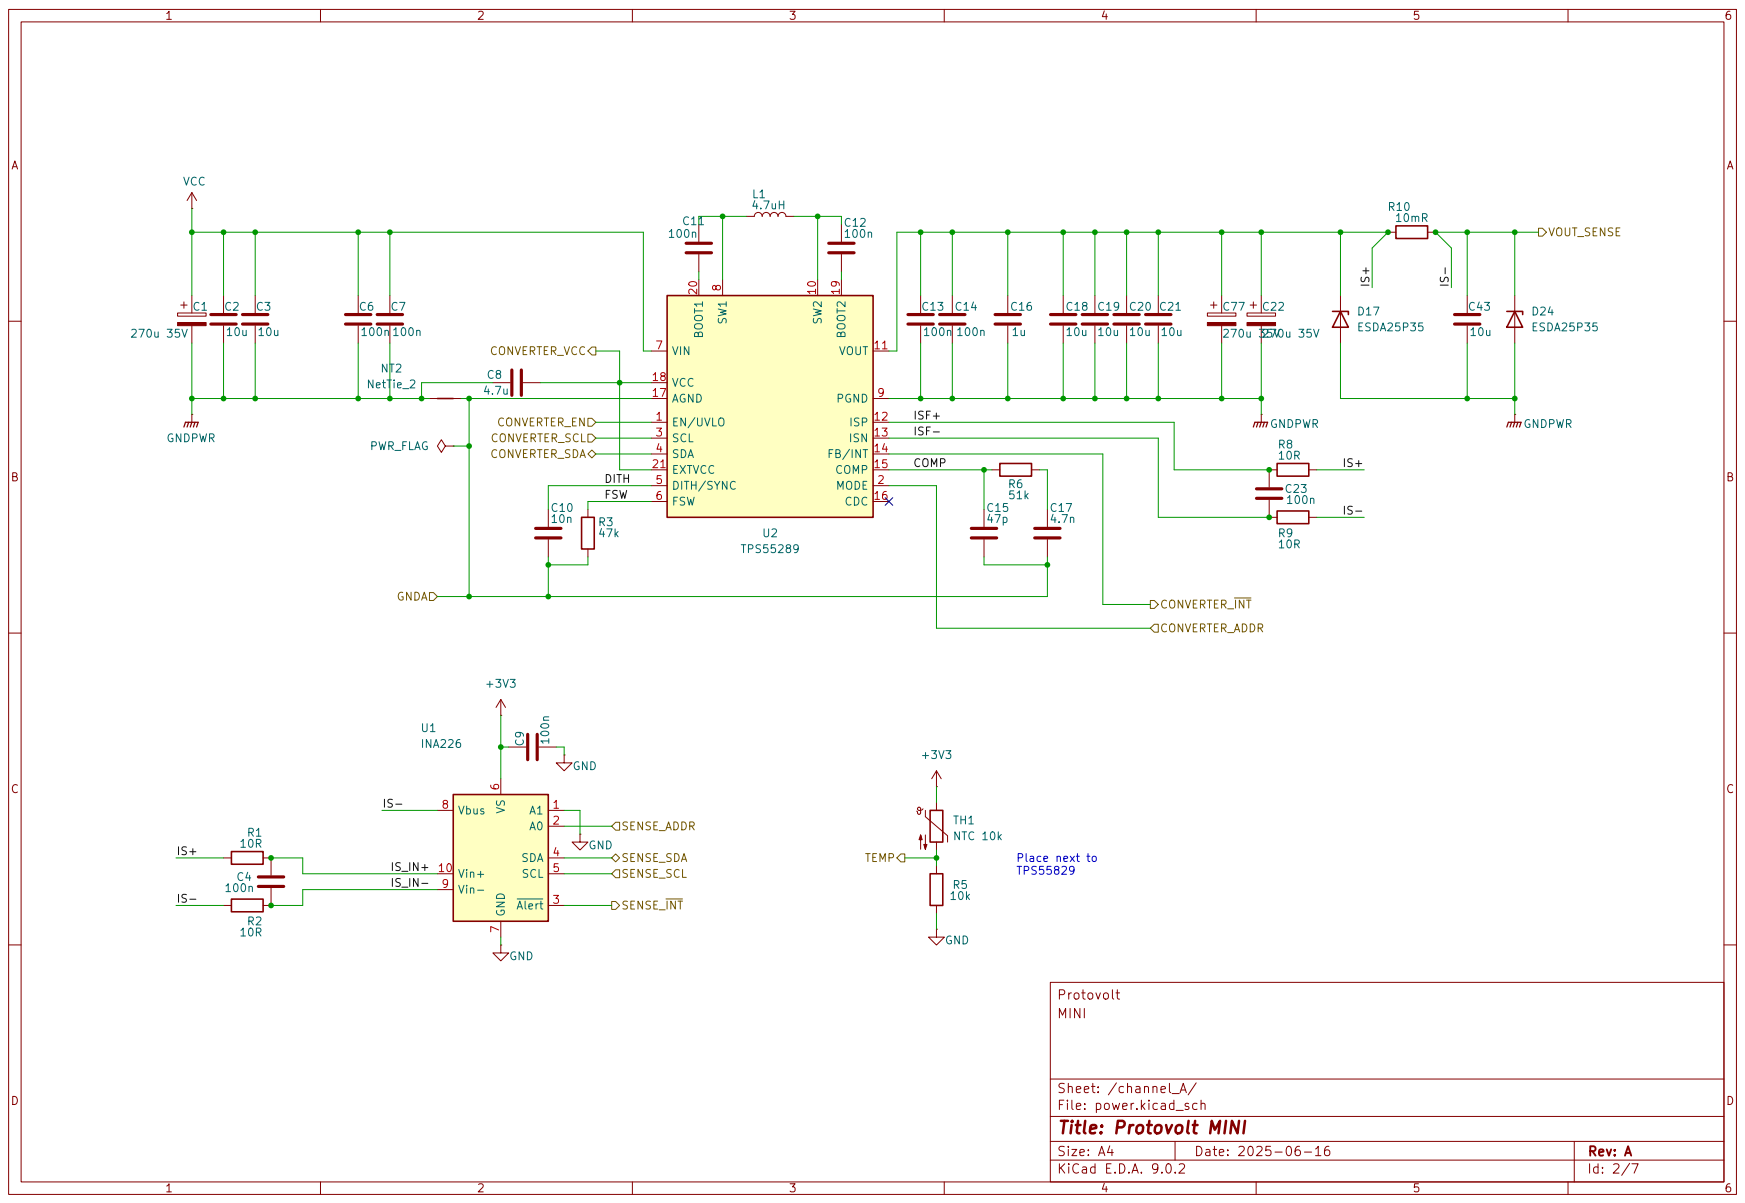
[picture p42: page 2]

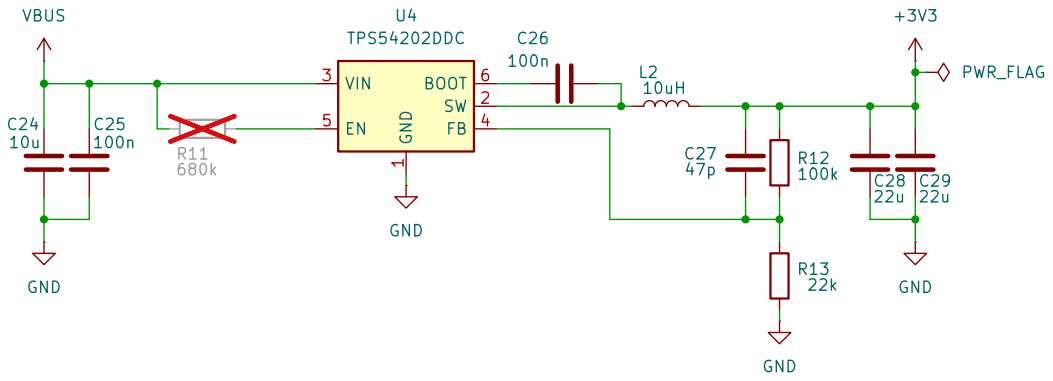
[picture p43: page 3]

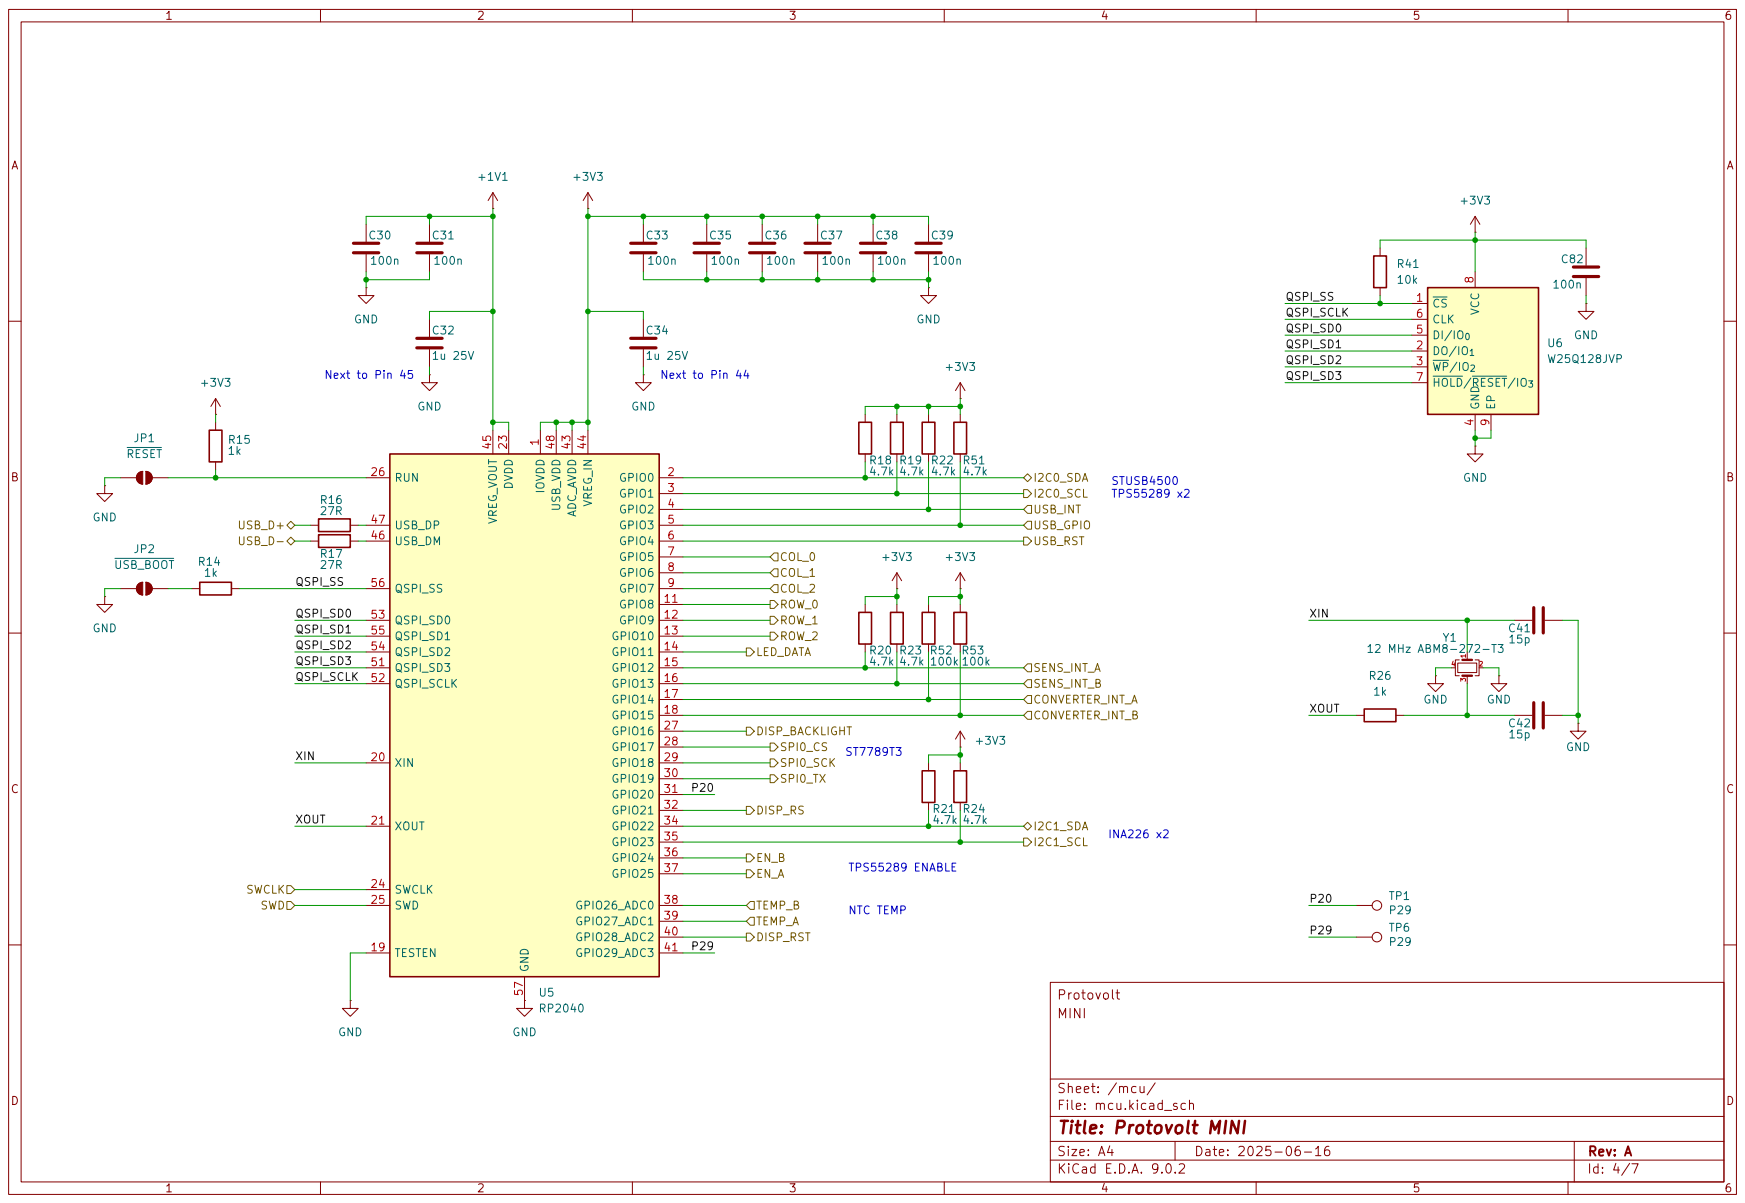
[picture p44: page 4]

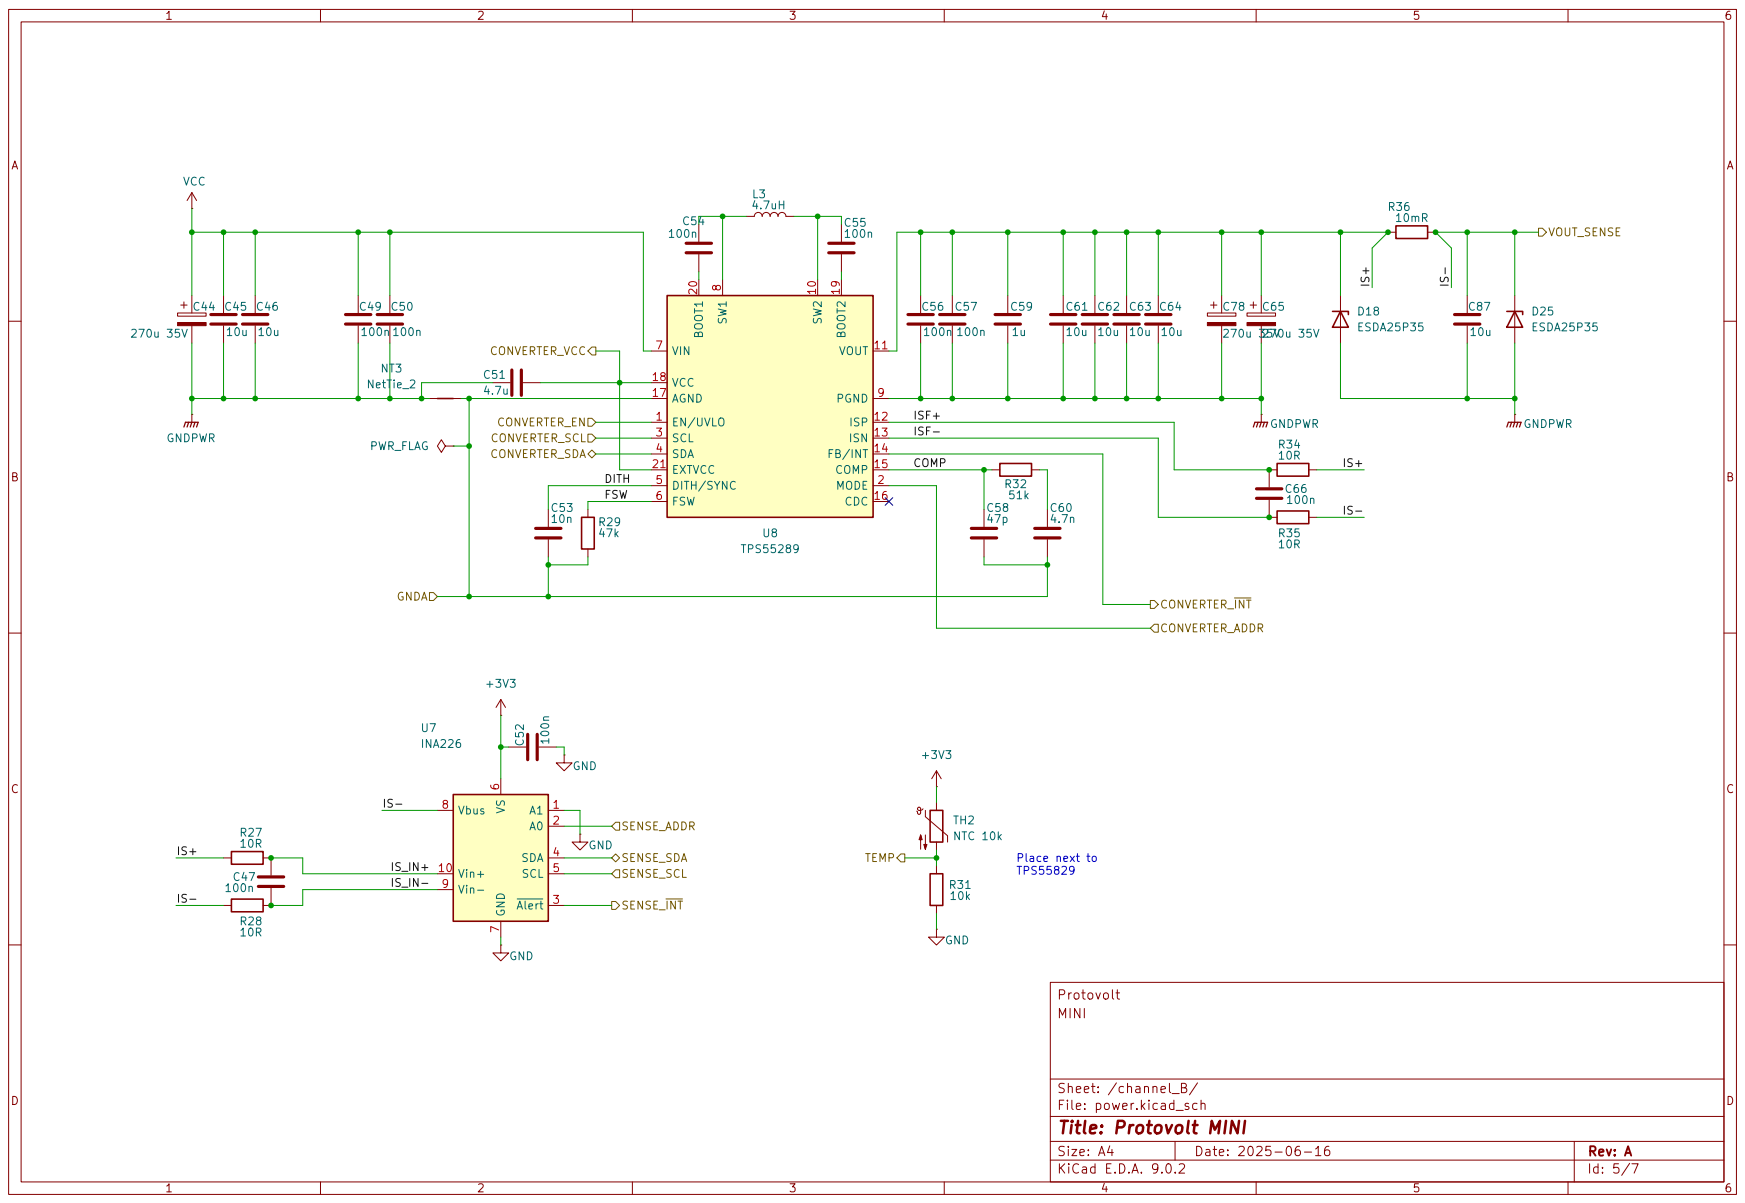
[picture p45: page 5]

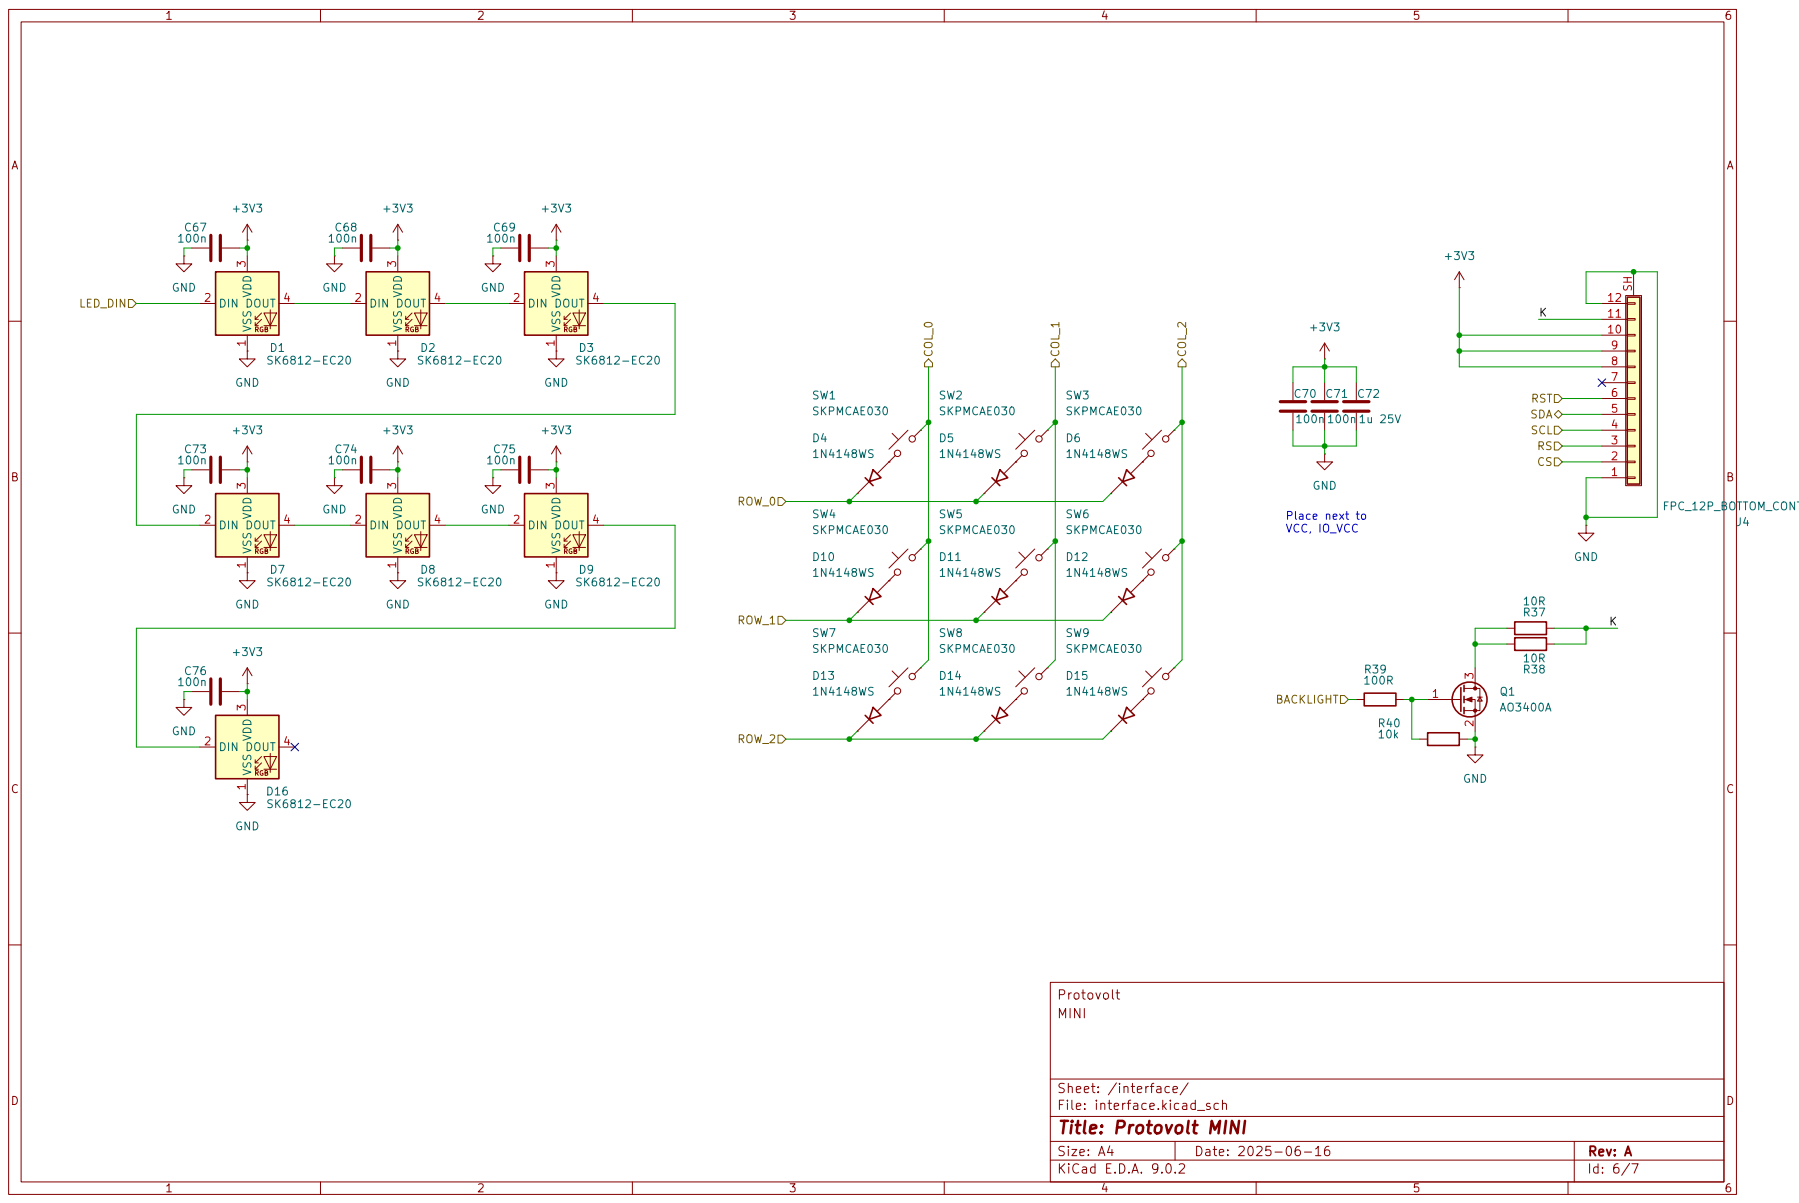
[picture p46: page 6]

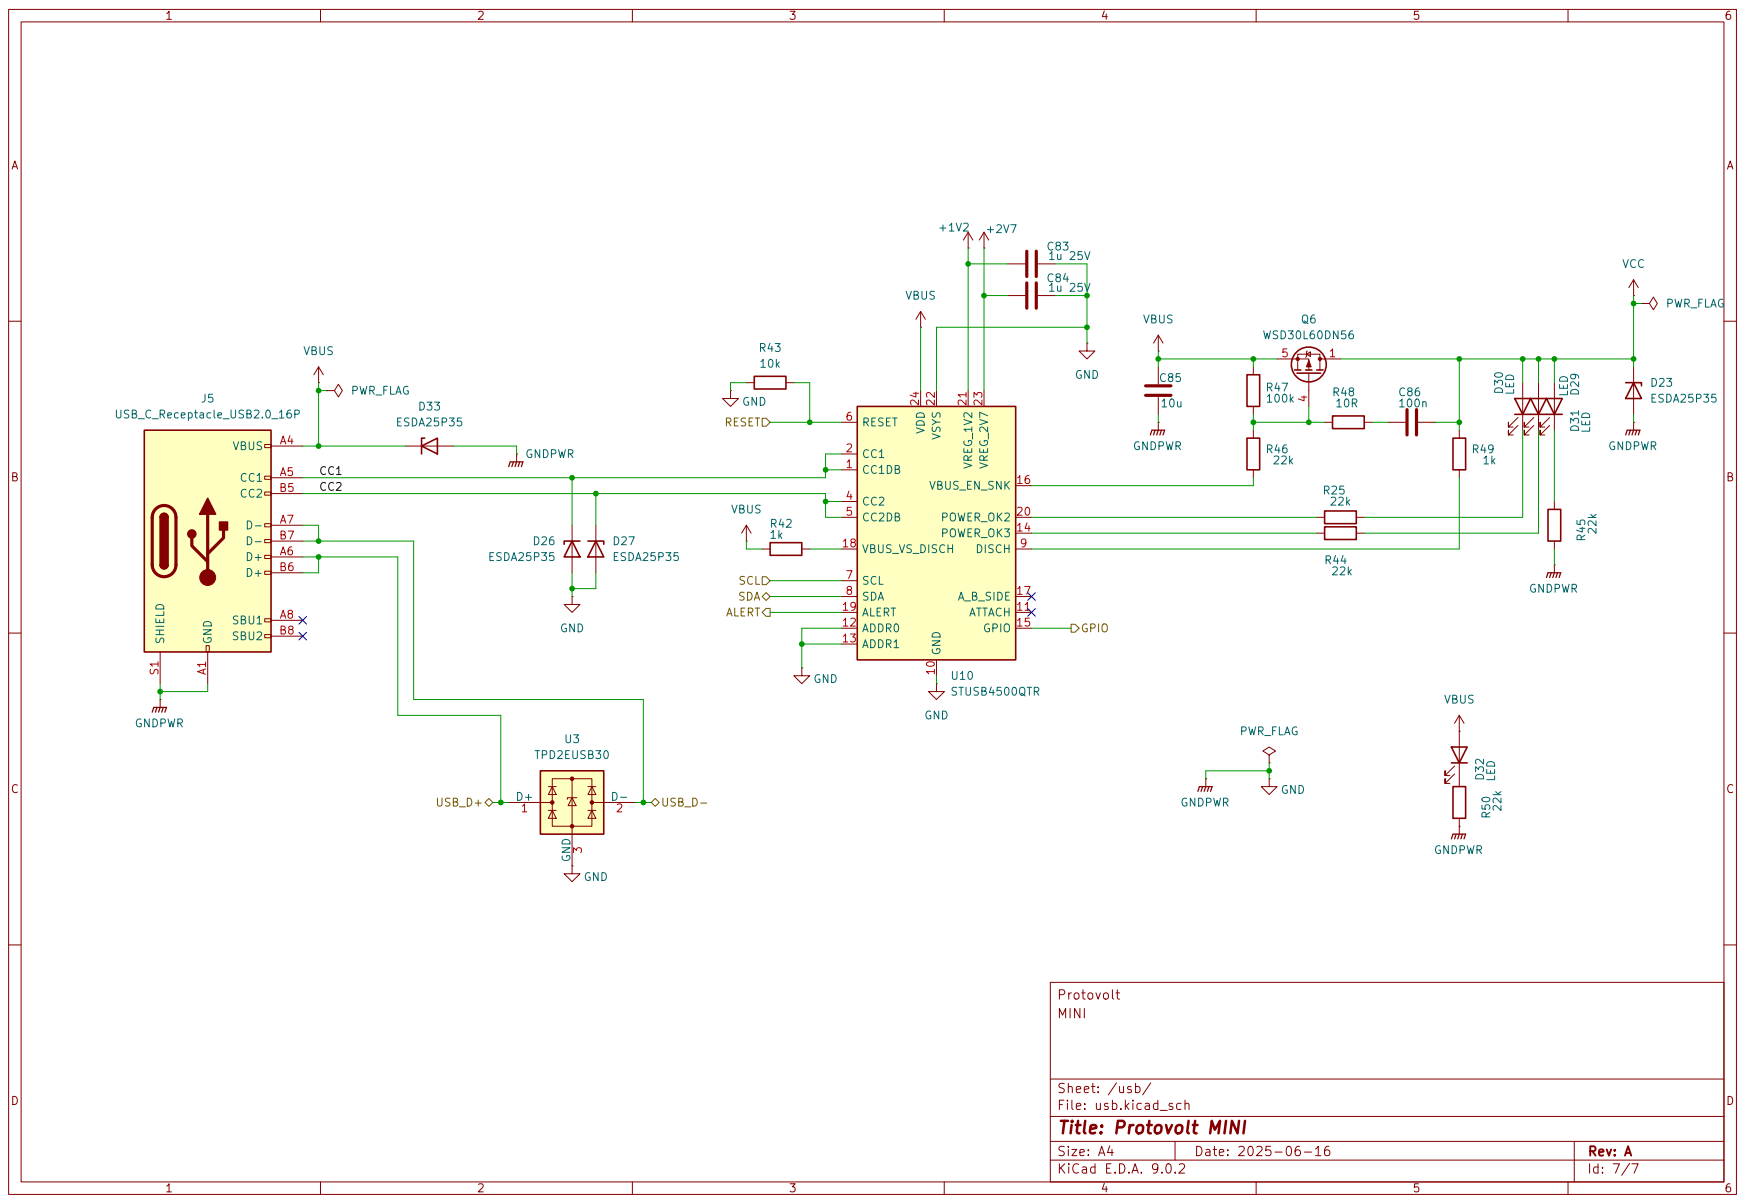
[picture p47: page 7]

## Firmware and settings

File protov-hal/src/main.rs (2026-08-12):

#![no_std]
#![no_main]

use protov_hal::{app, config, hal, scpi, task, ui_platform};

use core::cell::RefCell;

use defmt::*;
use embassy_executor::{Executor, Spawner};
use embassy_rp::adc::{self, Adc};
use embassy_rp::i2c::I2c;
use embassy_rp::multicore::{Stack, spawn_core1};
use embassy_rp::peripherals::{DMA_CH0, I2C0, I2C1, PIO0, USB};
use embassy_rp::pio;
use embassy_rp::pio::Pio;
use embassy_rp::spi::{self, Spi};
use embassy_rp::usb::{Driver, InterruptHandler};
use embassy_rp::{bind_interrupts, i2c};
use embassy_sync::blocking_mutex::Mutex;
use embassy_sync::blocking_mutex::raw::{NoopRawMutex, ThreadModeRawMutex};

use embassy_sync::blocking_mutex::Mutex as I2cMutex;

use embassy_sync::channel::{Channel, Sender};
use embassy_time::{Duration, Ticker, Timer};

use hal::backlight::Backlight;
use hal::display::DisplayInterface;
use hal::event::{AppEvent, HardwareEvent, InterfaceEvent, Task};
use hal::firmware;
use hal::interface::{ButtonsInterface, matrix};
use hal::watchdog;

use app::App;
use protov_ui::{DisplayGeometry, UiPlatform, UiRenderer};
use task::{
    DfuOutcome, handle_dfu_task, handle_display_task, handle_hardware_task, is_dfu_hardware_task,
    run_followup_tasks,
};
use ui_platform::HalPlatform;

use hal::event::{
    AppTask, AppTaskBuilder, Channel as OutputChannel, DfuStatus, DisplayTask, HardwareTask,
    PowerType,
};
use hal::led::LedsInterface;
use hal::temperature::TemperatureReading;
use hal::{
    Hal, HalSense, HalTempSense, INA226_DUMP_REQ, INA226_DUMP_RESP, SENSE_CHANNEL, converter_a_irq,
    converter_b_irq, poll_sense, temp_sense,
};
use scpi::RegisterChannelExt;
use scpi::parser::ScpiCommand;
use scpi::state::ScpiState;
use scpi::usb::{build_usb_cdc, fwup_payload, fwup_payload_len, spawn_usb_tasks};
use scpi::{RESPONSE_BUF, SCPI_CMD, SCPI_RESP, ScpiContext, ScpiResponse};

use static_cell::StaticCell;

use {defmt_rtt as _, panic_probe as _};

// Static channels
pub static INTERFACE_CHANNEL: Channel<ThreadModeRawMutex, InterfaceEvent, 32> = Channel::new();

const HW_CH_SIZE: usize = 32;
pub static HARDWARE_CHANNEL: Channel<ThreadModeRawMutex, HardwareEvent, HW_CH_SIZE> =
    Channel::new();
pub type HardwareChannelSender = hal::HardwareChannelSender;

// Multicore setup
static mut CORE1_STACK: Stack<8192> = Stack::new();
static EXECUTOR1: StaticCell<Executor> = StaticCell::new();

static BUTTONS_INTERFACE: StaticCell<ButtonsInterface> = StaticCell::new();

type StaticI2c0 = I2c<'static, I2C0, i2c::Blocking>;
type StaticI2c0Bus = Mutex<NoopRawMutex, RefCell<StaticI2c0>>;
static I2C0_BUS: StaticCell<StaticI2c0Bus> = StaticCell::new();

type StaticI2c1 = I2c<'static, I2C1, i2c::Blocking>;
type StaticI2c1Bus = Mutex<NoopRawMutex, RefCell<StaticI2c1>>;
static I2C1_BUS: StaticCell<StaticI2c1Bus> = StaticCell::new();

type StaticHalSense = HalSense<'static, NoopRawMutex, StaticI2c1>;
static HAL_SENSE: StaticCell<StaticHalSense> = StaticCell::new();

type StaticHalTempSense = HalTempSense<'static>;
static HAL_TEMP_SENSE: StaticCell<StaticHalTempSense> = StaticCell::new();

static SCPI_STATE: StaticCell<ScpiState> = StaticCell::new();

bind_interrupts!(struct Irqs {
    PIO0_IRQ_0 => pio::InterruptHandler<PIO0>;
    DMA_IRQ_0 => embassy_rp::dma::InterruptHandler<DMA_CH0>;
    ADC_IRQ_FIFO => adc::InterruptHandler;
    USBCTRL_IRQ => InterruptHandler<USB>;
});

const FWUP_APPL_RESET_DELAY_MS: u64 = 200;

#[embassy_executor::main]
async fn main(spawner: Spawner) {
    let p = embassy_rp::init(Default::default());

    // Confirm swap / clear stale bootloader state before any other init (Embassy b.rs).
    let fw_ctx = firmware::init(p.FLASH);
    watchdog::init(p.WATCHDOG);
    watchdog::stop_bootloader();
    watchdog::cancel_after_boot();

    // USB must start before any lengthy blocking init — the host will enumerate
    // and SET_CONFIGURATION while we are still booting otherwise (error -110).
    let usb_driver = Driver::new(p.USB, Irqs);
    let usb_resources = build_usb_cdc(usb_driver);
    spawn_usb_tasks(&spawner, usb_resources);

    // Power hardware initialization
    let i2c0 = I2c::new_blocking(p.I2C0, p.PIN_1, p.PIN_0, i2c::Config::default());
    let i2c0_bus: Mutex<NoopRawMutex, _> = I2cMutex::new(RefCell::new(i2c0));
    let i2c0_bus = I2C0_BUS.init(i2c0_bus);

    let i2c1 = I2c::new_blocking(p.I2C1, p.PIN_23, p.PIN_22, i2c::Config::default());
    let i2c1_bus: Mutex<NoopRawMutex, _> = I2cMutex::new(RefCell::new(i2c1));
    let i2c1_bus = I2C1_BUS.init(i2c1_bus);

    // Power hardware interrupts initialization
    spawner.spawn(unwrap!(converter_a_irq(
        HARDWARE_CHANNEL.sender(),
        p.PIN_15
    )));
    spawner.spawn(unwrap!(converter_b_irq(
        HARDWARE_CHANNEL.sender(),
        p.PIN_14
    )));

    // Output measurement loop
    let hal_sense = HalSense::new(i2c1_bus);
    let hal_sense = HAL_SENSE.init(hal_sense);
    spawner.spawn(unwrap!(poll_sense(
        hal_sense,
        SENSE_CHANNEL.receiver(),
        HARDWARE_CHANNEL.sender()
    )));

    // Temperature sense loop
    let adc: Adc<'_, adc::Async> = Adc::new(p.ADC, Irqs, adc::Config::default());
    let hal_temp_sense = HalTempSense::new(adc, p.PIN_26, p.PIN_27, p.ADC_TEMP_SENSOR);
    let hal_temp_sense = HAL_TEMP_SENSE.init(hal_temp_sense);
    spawner.spawn(unwrap!(temp_sense(
        hal_temp_sense,
        HARDWARE_CHANNEL.sender()
    )));

    let mut hal = Hal::new(i2c0_bus, i2c0_bus, p.PIN_24, p.PIN_25);

    let scpi_state = SCPI_STATE.init(ScpiState::default());
    let mut last_temp = TemperatureReading {
        ch_a: config::BOOT_TEMP_CH_A,
        ch_b: config::BOOT_TEMP_CH_B,
        mcu: config::BOOT_TEMP_MCU,
    };
    let mut input_voltage = 20.0f32;
    let mut input_current = 0.35f32;
    let mut input_type_pd = true;
    let mut power_type = PowerType::default();
    let mut last_serial_connected = scpi::serial_connected();

    // Buttons (moved to static so Core 1 owns them)
    let buttons = ButtonsInterface::new(
        [p.PIN_8.into(), p.PIN_9.into(), p.PIN_10.into()],
        [p.PIN_5.into(), p.PIN_6.into(), p.PIN_7.into()],
    );
    let buttons = BUTTONS_INTERFACE.init(buttons);

    // SPI display setup
    let spi = Spi::new_blocking(p.SPI0, p.PIN_18, p.PIN_19, p.PIN_20, spi::Config::default());
    let spi_shared: Mutex<NoopRawMutex, _> = Mutex::new(RefCell::new(spi));
    let mut display = DisplayInterface::new(&spi_shared, p.PIN_17, p.PIN_21, p.PIN_28);
    let backlight = Backlight::new(p.PWM_SLICE0, p.PIN_16);

    // Interfacing LEDs setup
    let pio = Pio::new(p.PIO0, Irqs);
    let leds = LedsInterface::new(pio, p.DMA_CH0, Irqs, p.PIN_11);

    // App logic
    let mut app = App::default();
    let mut platform = HalPlatform::new(backlight, leds);
    let mut ui = UiRenderer::new(&mut display.target, DisplayGeometry::default());
    ui.clear(&mut platform).unwrap();
    platform.set_lcd_brightness(scpi_state.lcd_brightness);

    // Start core 1 and spawn poll_interface there
    spawn_core1(
        p.CORE1,
        unsafe { &mut *core::ptr::addr_of_mut!(CORE1_STACK) },
        move || {
            let executor1 = EXECUTOR1.init(Executor::new());
            executor1.run(|spawner| {
                spawner.spawn(unwrap!(poll_interface(buttons, INTERFACE_CHANNEL.sender())));
            });
        },
    );

    // Start application
    let hw_sender = HARDWARE_CHANNEL.sender();
    hw_sender.send(HardwareEvent::PowerOn).await;
    let int_sender = INTERFACE_CHANNEL.sender();

    let mut ticker = Ticker::every(Duration::from_hz(100));
    let mut poll_counter = 0u32;

    loop {
        if scpi_state.lcd_brightness != platform.lcd_brightness() {
            platform.set_lcd_brightness(scpi_state.lcd_brightness);
        }

        if let Ok(cmd) = SCPI_CMD.try_receive() {
            let ctx = build_scpi_context(
                &app,
                &last_temp,
                input_type_pd,
                input_voltage,
                input_current,
                scpi_state,
                firmware::flash_unique_id(),
            );
            let (mut response, tasks) = match cmd {
                ScpiCommand::Ina226RegQuery { channel } => {
                    INA226_DUMP_REQ.send(channel.to_hal()).await;
                    let response = match INA226_DUMP_RESP.receive().await {
                        Ok(text) => ScpiResponse::with_text(text),
                        Err(()) => {
                            scpi_state.push_error(-200, "Register dump unavailable");
                            ScpiResponse::none()
                        }
                    };
                    (response, None)
                }
                ScpiCommand::Tps55289RegQuery { channel } => {
                    let mut buf = heapless::String::<RESPONSE_BUF>::new();
                    let response = if hal.dump_tps55289(channel.to_hal(), &mut buf).is_ok() {
                        ScpiResponse::with_text(buf)
                    } else {
                        scpi_state.push_error(-200, "Register dump unavailable");
                        ScpiResponse::none()
                    };
                    (response, None)
                }
                ScpiCommand::FwupData => {
                    let result = app.handle_fwup_data(fwup_payload_len() as u32, scpi_state);
                    (result.response, result.tasks)
                }
                ScpiCommand::FwupAbor => {
                    let result = app.handle_scpi(cmd, scpi_state, &ctx);
                    fw_ctx.dfu_abort();
                    (result.response, result.tasks)
                }
                _ => {
                    let result = app.handle_scpi(cmd, scpi_state, &ctx);
                    (result.response, result.tasks)
                }
            };
            let mut fwup_appl_outcome = None;
            if let Some(tasks) = tasks {
                for slot in tasks.tasks[..tasks.count].iter().filter_map(|t| t.as_ref()) {
                    if let Task::Display(disp_task) = slot {
                        handle_display_task(
                            *disp_task,
                            &mut ui,
                            &mut platform,
                            scpi_state,
                            &hw_sender,
                            &int_sender,
                        )
                        .await;
                    }
                }

                for task in tasks {
                    match task {
                        Task::Display(_) => {}
                        Task::Hardware(hw_task) if is_dfu_hardware_task(&hw_task) => {
                            match handle_dfu_task(
                                hw_task,
                                fw_ctx,
                                &mut app,
                                scpi_state,
                                fwup_payload(),
                            ) {
                                DfuOutcome::VerifySucceeded(extra) => {
                                    fwup_appl_outcome = Some(true);
                                    if let Some(extra) = extra {
                                        run_followup_tasks(
                                            extra,
                                            &mut ui,
                                            &mut platform,
                                            scpi_state,
                                            &hw_sender,
                                            &int_sender,
                                        )
                                        .await;
                                    }
                                }
                                DfuOutcome::VerifyFailed(extra) => {
                                    fwup_appl_outcome = Some(false);
                                    fw_ctx.dfu_abort();
                                    if let Some(extra) = extra {
                                        run_followup_tasks(
                                            extra,
                                            &mut ui,
                                            &mut platform,
                                            scpi_state,
                                            &hw_sender,
                                            &int_sender,
                                        )
                                        .await;
                                    }
                                }
                                DfuOutcome::Progress(extra) => {
                                    if let Some(extra) = extra {
                                        run_followup_tasks(
                                            extra,
                                            &mut ui,
                                            &mut platform,
                                            scpi_state,
                                            &hw_sender,
                                            &int_sender,
                                        )
                                        .await;
                                    }
                                }
                            }
                        }
                        Task::Hardware(hw_task) => {
                            handle_hardware_task(hw_task, &mut hal, &hw_sender, &int_sender).await;
                        }
                    }
                }
            }
            if let Some(success) = fwup_appl_outcome {
                response = app.fwup_appl_response(success, scpi_state);
            }
            SCPI_RESP.send(response).await;
            if fwup_appl_outcome == Some(true) {
                handle_display_task(
                    DisplayTask::DfuStatus(DfuStatus::Flashing),
                    &mut ui,
                    &mut platform,
                    scpi_state,
                    &hw_sender,
                    &int_sender,
                )
                .await;
                Timer::after(Duration::from_millis(FWUP_APPL_RESET_DELAY_MS)).await;
                firmware::dfu_reset_after_verify();
            }
        }

        let mut tasks = AppTaskBuilder::new();
        let mut pending_readout_a = None;
        let mut pending_readout_b = None;

        while let Ok(hw_event) = HARDWARE_CHANNEL.try_receive() {
            match hw_event {
                HardwareEvent::TempAcquired(temp) => {
                    last_temp = temp;
                    tasks =
                        append_app_event(tasks, &mut app, scpi_state, AppEvent::Hardware(hw_event));
                }
                HardwareEvent::PowerDeliveryReady(pt) => {
                    power_type = pt;
                    match pt {
                        hal::event::PowerType::PowerDelivery(limits) => {
                            input_type_pd = true;
                            input_voltage = limits.voltage;
                            input_current = limits.current;
                        }
                        hal::event::PowerType::Standard(limits) => {
                            input_type_pd = false;
                            input_voltage = limits.voltage;
                            input_current = limits.current;
                        }
                    }
                    tasks = append_app_event(
                        tasks,
                        &mut app,
                        scpi_state,
                        AppEvent::Hardware(HardwareEvent::PowerDeliveryReady(pt)),
                    );
                }
                HardwareEvent::ReadoutAcquired(channel, readout) => match channel {
                    OutputChannel::A => pending_readout_a = Some(readout),
                    OutputChannel::B => pending_readout_b = Some(readout),
                },
                other => {
                    tasks =
                        append_app_event(tasks, &mut app, scpi_state, AppEvent::Hardware(other));
                }
            }
        }

        if let Some(readout) = pending_readout_a {
            tasks = append_app_event(
                tasks,
                &mut app,
                scpi_state,
                AppEvent::Hardware(HardwareEvent::ReadoutAcquired(OutputChannel::A, readout)),
            );
        }
        if let Some(readout) = pending_readout_b {
            tasks = append_app_event(
                tasks,
                &mut app,
                scpi_state,
                AppEvent::Hardware(HardwareEvent::ReadoutAcquired(OutputChannel::B, readout)),
            );
        }

        let mut last_ui_event = None;
        while let Ok(ui_event) = INTERFACE_CHANNEL.try_receive() {
            last_ui_event = Some(ui_event);
        }
        if let Some(ui_event) = last_ui_event {
            tasks = append_app_event(tasks, &mut app, scpi_state, AppEvent::Interface(ui_event));
        }

        poll_counter = poll_counter.wrapping_add(1);
        if app.is_standby() && poll_counter >= 20 {
            poll_counter = 0;
            tasks = tasks
                .hardware(HardwareTask::PollConverterStatus(OutputChannel::A))
                .hardware(HardwareTask::PollConverterStatus(OutputChannel::B));
        }

        let serial_connected = scpi::serial_connected();
        if serial_connected != last_serial_connected && app.is_standby() {
            last_serial_connected = serial_connected;
            handle_display_task(
                DisplayTask::UpdatePowerInfo(power_type),
                &mut ui,
                &mut platform,
                scpi_state,
                &hw_sender,
                &int_sender,
            )
            .await;
        }

        if let Some(app_task) = tasks.build() {
            for task in app_task {
                match task {
                    Task::Hardware(hw_task) => {
                        handle_hardware_task(hw_task, &mut hal, &hw_sender, &int_sender).await;
                    }
                    Task::Display(disp_task) => {
                        handle_display_task(
                            disp_task,
                            &mut ui,
                            &mut platform,
                            scpi_state,
                            &hw_sender,
                            &int_sender,
                        )
                        .await
                    }
                }
            }
        }

        ticker.next().await;
    }
}

fn append_app_event(
    mut tasks: AppTaskBuilder,
    app: &mut App,
    scpi: &mut ScpiState,
    event: AppEvent,
) -> AppTaskBuilder {
    if let Some(produced) = app.handle_event(event, scpi) {
        tasks = tasks.extend(app_task_into_builder(produced));
    }
    tasks
}

fn app_task_into_builder(task: AppTask) -> AppTaskBuilder {
    let mut builder = AppTaskBuilder::new();
    for item in task {
        builder = match item {
            Task::Hardware(hw) => builder.hardware(hw),
            Task::Display(disp) => builder.display(disp),
        };
    }
    builder
}

fn build_scpi_context(
    _app: &App,
    temp: &TemperatureReading,
    input_type_pd: bool,
    input_voltage: f32,
    input_current: f32,
    scpi_state: &ScpiState,
    flash_unique_id: &[u8; 8],
) -> ScpiContext {
    let prot_a = scpi_state.prot_latched(scpi::ScpiChannel::Ch1);
    let prot_b = scpi_state.prot_latched(scpi::ScpiChannel::Ch2);
    let sense_ok = !prot_a && !prot_b;
    ScpiContext {
        temp_ch_a: temp.ch_a,
        temp_ch_b: temp.ch_b,
        temp_mcu: temp.mcu,
        input_type_pd,
        input_voltage,
        input_current,
        sense_ok,
        converter_ok: sense_ok,
        prot_latched_a: prot_a,
        prot_latched_b: prot_b,
        flash_unique_id: *flash_unique_id,
    }
}

#[embassy_executor::task]
async fn poll_interface(
    buttons: &'static mut ButtonsInterface<'static>,
    channel: Sender<'static, ThreadModeRawMutex, InterfaceEvent, 32>,
) {
    let mut ticker = Ticker::every(Duration::from_millis(matrix::POLL_TIME_MS));
    loop {
        if let Some(event) = buttons.poll() {
            let _ = channel.try_send(event);
        }
        ticker.next().await;
    }
}

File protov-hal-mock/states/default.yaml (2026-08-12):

description: Post-boot standby main screen
idn:
  serial: "550e8400"
  fw_version: "1.0.0"
  hw_version: "A.1"
remote: true
hardware_state: Standby
interface:
  selected_channel: A
  settings_open: false
  set_state: set
  arrows_function: navigation
  set_select: voltage
power:
  kind: standard
  voltage: 5.0
  current: 0.5
  serial_connected: false
ui: main
channels:
  CH1:
    voltage: 5.0
    current: 1.0
    ovp: 20.0
    ocp: 5.0
    output: false
  CH2:
    voltage: 3.3
    current: 1.0
    ovp: 20.0
    ocp: 5.0
    output: false

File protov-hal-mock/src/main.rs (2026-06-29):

use clap::Parser;
use protov_hal_mock::{RunningServer, ServerConfig};
use tracing_subscriber::EnvFilter;

#[derive(Parser, Debug)]
#[command(name = "protov-mock", about = "ProtoV MINI WebSocket simulator")]
struct Args {
    #[arg(long, default_value = "127.0.0.1")]
    bind: String,

    #[arg(long, env = "PROTOV_MOCK_SCPI_PORT", default_value_t = 8765)]
    scpi_port: u16,

    #[arg(long, env = "PROTOV_MOCK_CTRL_PORT", default_value_t = 8766)]
    control_port: u16,
}

#[tokio::main]
async fn main() -> std::io::Result<()> {
    tracing_subscriber::fmt()
        .with_env_filter(
            EnvFilter::from_default_env().add_directive("protov_hal_mock=info".parse().unwrap()),
        )
        .init();

    let args = Args::parse();
    let config = ServerConfig {
        bind: args.bind,
        scpi_port: args.scpi_port,
        control_port: args.control_port,
    };

    let server = RunningServer::start(config).await?;
    tracing::info!(
        scpi = %server.scpi_addr,
        control = %server.control_addr,
        "ProtoV mock server running; press Ctrl+C to exit"
    );

    tokio::signal::ctrl_c().await?;
    tracing::info!("shutting down");
    server.shutdown();
    Ok(())
}

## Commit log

2025-05-11 kicad .gitignore
2025-05-11 LM51772 buck/boost base
    [output_A.kicad_sch, protovolt.kicad_pcb, protovolt.kicad_sch]
2025-05-14 finish demo schematic
    [output_A.kicad_sch, power.kicad_sch, protovolt.kicad_sch]
2025-05-15 route h-bridge
    [output_A.kicad_sch, protovolt.kicad_pcb]
2025-05-15 fet routing
    [output_A.kicad_sch, protovolt.kicad_pcb]
2025-05-16 four layer
    [CIP1040.step, output_A.kicad_sch, protovolt.kicad_pcb]
2025-05-16 wire all
    [output_A.kicad_sch, protovolt.kicad_pcb]
2025-05-16 route ground
    [protovolt.kicad_pcb]
2025-05-17 finalize DRU & PCB
    [bom.csv, output_A.kicad_sch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]
2025-05-17 pnp files
    [protovolt-bottom-pos.csv, protovolt-top-pos.csv]
2025-05-17 replace parts
    [output_A.kicad_sch, protovolt.kicad_pcb]
2025-05-18 retrace all
    [bom.csv, output_A.kicad_sch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]
2025-05-18 add BOM
    [protovolt.csv]
2025-05-18 add basic parts
    [output_A.kicad_sch, protovolt.csv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]
2025-05-19 order batch
    [protovolt.csv]
2025-05-19 cleanup source
    [CIP1040.step, output_A.kicad_sch, power.kicad_sch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]
2025-05-19 implement TPS55289
    [mini.kicad_sch, power.kicad_sch, regulation.kicad_sch]
2025-06-05 add interface & RP2040
    [interface.kicad_sch, mcu.kicad_sch, measurement.kicad_sch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]
2025-06-08 finalize parts in schematic
    [interface.kicad_sch, mcu.kicad_sch, measurement.kicad_sch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]
2025-06-09 route most
    [interface.kicad_sch, mcu.kicad_sch, mini.kicad_sch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]
2025-06-09 ERC run
    [interface.kicad_sch, mcu.kicad_sch, mini.kicad_sch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]
2025-06-09 assign footprints & LCSC id
    [interface.kicad_sch, mcu.kicad_sch, mini.kicad_sch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]
2025-06-09 build all footprints
    [interface.kicad_sch, power.kicad_sch, usb.kicad_sch]
2025-06-09 import to PCB
    [mcu.kicad_sch, mini.kicad_sch, power.kicad_sch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]
2025-06-09 place ui elements
    [interface.kicad_sch, mini.kicad_sch]
2025-06-10 route power stage
    [interface.kicad_sch, mcu.kicad_sch, mini.kicad_sch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]
2025-06-11 route digitals
    [interface.kicad_sch, mcu.kicad_sch, mini.kicad_sch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]
2025-06-11 route simple traces
    [usb.kicad_sch]
2025-06-11 route sense lines
    [power.kicad_sch]
2025-06-12 put FPC to front & rearrange buck/boost
    [power.kicad_sch]
2025-06-12 route power
    [power.kicad_sch, usb.kicad_sch]
2025-06-14 reroute all except 3V3 & GND
    [interface.kicad_sch, mini.kicad_sch, power.kicad_sch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]
2025-06-16 finish routing
    [mini.kicad_sch, power.kicad_sch, regulation.kicad_sch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]
2025-06-16 all DRC except silkscreen warnings
    [mini.kicad_sch]
2025-06-16 fix diode footprint
    [interface.kicad_sch]
2025-06-16 finalize routing
    [mini.kicad_sch]
2025-06-16 cleanup schematic
    [interface.kicad_sch, mcu.kicad_sch, mini.kicad_sch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]
2025-06-21 first fab run
    [interface.kicad_sch, mcu.kicad_sch, power.kicad_sch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]
2025-06-22 use framebuf
2025-06-23 navbar buttons
2025-06-23 buttons select
2025-06-23 setpoint type switch
2025-06-27 setpoint modify without buffer & clamping
2025-07-01 button interfacing
2025-07-08 add channel leds
2025-07-08 add other leds color
2025-07-08 refactor i2c hal
2025-07-09 basic power systems
2025-07-09 basic output voltage level modification
2025-07-09 power discharge + current limiting
2025-07-27 flip channels & correct order
    [main.rs]
2025-07-28 switch converters
2025-07-28 remove kicad backups
2025-10-23 calibrate TPS55289 output voltage
2025-11-23 add devices cards
2025-11-23 add disable all button
2025-11-23 invidiual devices channels
2026-01-22 base temperature measurement hal
2026-01-23 add current mode readback
2026-06-27 increase task arena size & fix hardfault races on hardware channel mut
    [main.rs]
2026-06-27 add UI app flow unit tests
2026-06-29 add assigned PID 0x112B from RPI
2026-07-06 add proper firmware swap cancelation policy
    [main.rs, task.rs]
2026-07-07 bump to v1.5.4: add SCPI DFU to mock device
2026-07-07 nvm flash driver for SYST:IDAT? query
2026-07-16 add note about bootloader debug mode for probe-rs
2026-07-20 add power source compatibility issue template
2026-07-20 add power sources testing issue link
